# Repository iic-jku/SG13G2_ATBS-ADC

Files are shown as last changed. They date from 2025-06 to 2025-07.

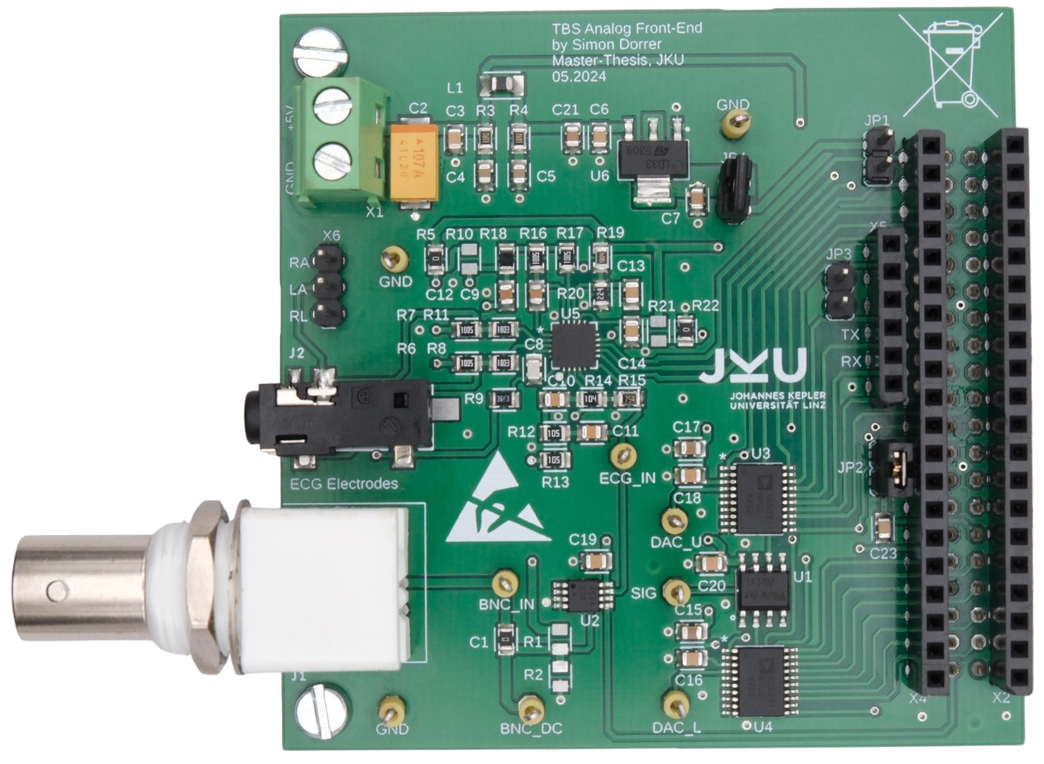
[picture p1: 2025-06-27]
PCB-Design/TBS_Analog_Front-End/TBS_Analog_Front-End_Pics/TBS_Analog_Front-End_TOP_3D_Foto.png

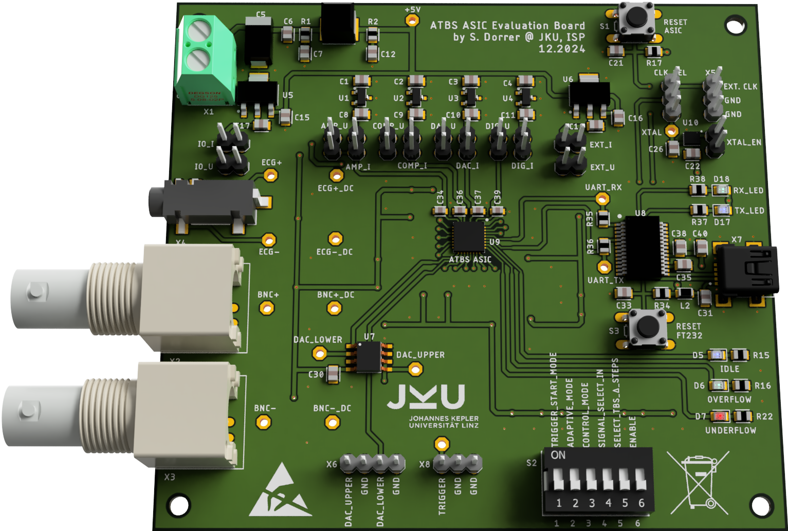
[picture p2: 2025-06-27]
PCB-Design/ATBS_Evaluation-Board/ATBS_Evaluation-Board_Pics/ATBS_Evaluation-Board_3D_Top.png

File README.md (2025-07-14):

# SG13G2_ATBS-ADC
**Author:** Simon Dorrer, 2024 / 2025, Johannes Kepler University (JKU) Linz, Austria, Institute for Integrated Circuits and Quantum Computing (IICQC) / Institute of Signal Processing (ISP). This ATBS-ADC has been designed in the context of a Master's thesis, it is published on https://epub.jku.at/obvulihs/content/titleinfo/12118473.

**Title:** An Open-Source Adaptive Event-Based ADC for Bio-Signal Acquisition in 130nm CMOS

**Abstract:**
Event-based ADCs offer significant advantages over Nyquist ADCs in applications where signals are sparse and exhibit substantial variations only within short time intervals, such as the QRS complex in an electrocardiogram (ECG). Unlike Nyquist ADCs, which sample data continuously at fixed rates and therefore often lead to unnecessary data and higher power consumption in time intervals of minimal signal variation, event-based ADCs only generate data when the signal exceeds a predefined voltage threshold. This makes them more energy-efficient, especially for battery-powered, wireless, and wearable devices, such as fitness trackers, medical sensors, and Internet of Things (IoT) devices. Adaptively adjusting these voltage thresholds further enhances efficiency.

This work first presents a PCB-level demonstrator to validate the feasibility of the event-based ADC concept. The demonstrator enables the development of a reconstruction framework for non-uniform data points in Matlab and Python and serves as a verification platform of the digital core on an FPGA.

Subsequently, an event-based ADC is integrated utilizing open-source tools and IHP's 130nm CMOS technology. The analog circuit design uses Xschem, Ngspice, and Jupyter notebooks with gm/ID sizing scripts. Furthermore, the design consists of a digital core written in VHDL. Since some open-source tools prefer Verilog, the VHDL code is converted to Verilog using GHDL. Simulations are conducted with GTKWave, Surfer, or ModelSim, while register-transfer level (RTL) synthesis is performed using Yosys. The synthesized digital design is included in Xschem using Qflow scripts and Xspice, enabling analog-mixed signal (AMS) simulations. The digital layout is created with OpenROAD Flow scripts (ORFS).

Finally, a pinout and a suitable package is suggested and a potential evaluation board for the designed ASIC is proposed.

**Cite this work:**

```
@online{Dorrer_2025_ATBS_ADC,
	author={Simon Dorrer},
	title={{An Open-Source Adaptive Event-Based ADC for Bio-Signal Acquisition in 130nm CMOS}},
	year={2025},
	url={https://github.com/iic-jku/SG13G2_ATBS-ADC}}
```

**Resources:**

- Master's Thesis: https://epub.jku.at/obvulihs/content/titleinfo/12118473
- Presentation at FSiC 2025: https://wiki.f-si.org/index.php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
- YouTube Video: coming soon on https://www.youtube.com/@Simi_OE3SDE
- GitHub Repository (SG13G2 ASIC Design Template):
  https://github.com/simi1505/SG13G2_ASIC-Design-Template

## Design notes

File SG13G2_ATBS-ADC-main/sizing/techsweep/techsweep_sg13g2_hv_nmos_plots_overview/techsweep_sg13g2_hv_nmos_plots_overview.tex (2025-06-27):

% !TeX TXS-program:compile = txs:///pdflatex/[--shell-escape]
%% !TeX document-id = {b8e7f259-21c3-4834-b29d-9cf620be8d99}

\documentclass[12pt]{article}

\usepackage[utf8]{inputenc}
\usepackage[T1]{fontenc}
\usepackage[ngerman, english]{babel}
\usepackage{lmodern}
\usepackage{geometry}
\usepackage{amsmath}
\usepackage{float}
\usepackage{graphicx}
\usepackage{subfig}

\begin{document}
	
	\oddsidemargin 0mm
	\parindent 0pt
	\newgeometry{top=2cm, bottom=2cm, left=2.6cm, right=3cm, footskip=30pt}
	
	\begin{figure}[!ht]
		\centering
		\vspace*{-18px}
		\subfloat[][]{}
		\hfill
		\subfloat[][]{} \\ \vspace{-10px}
		\subfloat[][]{}
		\hfill
		\subfloat[][Modelling issue]{} \\ \vspace{-10px}
		\subfloat[][]{}
		\hfill
		\subfloat[][]{} \\ \vspace{-10px}
		\subfloat[][]{}
		\hfill
		\subfloat[][]{}
		\caption{Characterization plots of a SG13G2 HV NMOST for the $g_\mathrm{m} / I_\mathrm{D}$ methodology.}
		\label{fig:NMOS_gmID_plots}
	\end{figure}
\end{document}

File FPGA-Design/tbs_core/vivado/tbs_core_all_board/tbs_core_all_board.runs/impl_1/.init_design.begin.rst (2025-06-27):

<?xml version="1.0"?>
<ProcessHandle Version="1" Minor="0">
    <Process Command=".planAhead." Owner="si150" Host="SIMIBOOK" Pid="18372">
    </Process>
</ProcessHandle>

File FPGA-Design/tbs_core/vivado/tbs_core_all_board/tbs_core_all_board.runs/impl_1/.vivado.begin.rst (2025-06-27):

<?xml version="1.0"?>
<ProcessHandle Version="1" Minor="0">
    <Process Command="vivado.bat" Owner="si150" Host="SIMIBOOK" Pid="11472" HostCore="16" HostMemory="016458313728">
    </Process>
</ProcessHandle>
<?xml version="1.0"?>
<ProcessHandle Version="1" Minor="0">
    <Process Command="vivado.bat" Owner="si150" Host="SIMIBOOK" Pid="11940" HostCore="16" HostMemory="016458313728">
    </Process>
</ProcessHandle>
<?xml version="1.0"?>
<ProcessHandle Version="1" Minor="0">
    <Process Command="vivado.bat" Owner="si150" Host="SIMIBOOK" Pid="7340" HostCore="16" HostMemory="016458313728">
    </Process>
</ProcessHandle>

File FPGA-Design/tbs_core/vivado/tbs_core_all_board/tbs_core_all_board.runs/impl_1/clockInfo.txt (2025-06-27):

-------------------------------------
| Tool Version : Vivado v.2024.1
| Date         : Tue Mar 25 13:14:02 2025
| Host         : SimiBook
| Design       : design_1
| Device       : xc7s25-ftgb196-1--
-------------------------------------

For more information on clockInfo.txt clock routing debug file see https://support.xilinx.com/s/article/000035660?language=en_US

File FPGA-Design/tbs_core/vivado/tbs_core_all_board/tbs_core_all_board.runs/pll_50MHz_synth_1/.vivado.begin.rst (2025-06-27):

<?xml version="1.0"?>
<ProcessHandle Version="1" Minor="0">
    <Process Command="vivado.bat" Owner="si150" Host="SIMIBOOK" Pid="6616" HostCore="16" HostMemory="016458313728">
    </Process>
</ProcessHandle>

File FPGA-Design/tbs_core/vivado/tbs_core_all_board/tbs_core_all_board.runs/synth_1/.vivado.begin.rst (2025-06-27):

<?xml version="1.0"?>
<ProcessHandle Version="1" Minor="0">
    <Process Command="vivado.bat" Owner="si150" Host="SIMIBOOK" Pid="9116" HostCore="16" HostMemory="016458313728">
    </Process>
</ProcessHandle>

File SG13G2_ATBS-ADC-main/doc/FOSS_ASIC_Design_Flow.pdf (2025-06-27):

# FOSS ASIC DESIGN

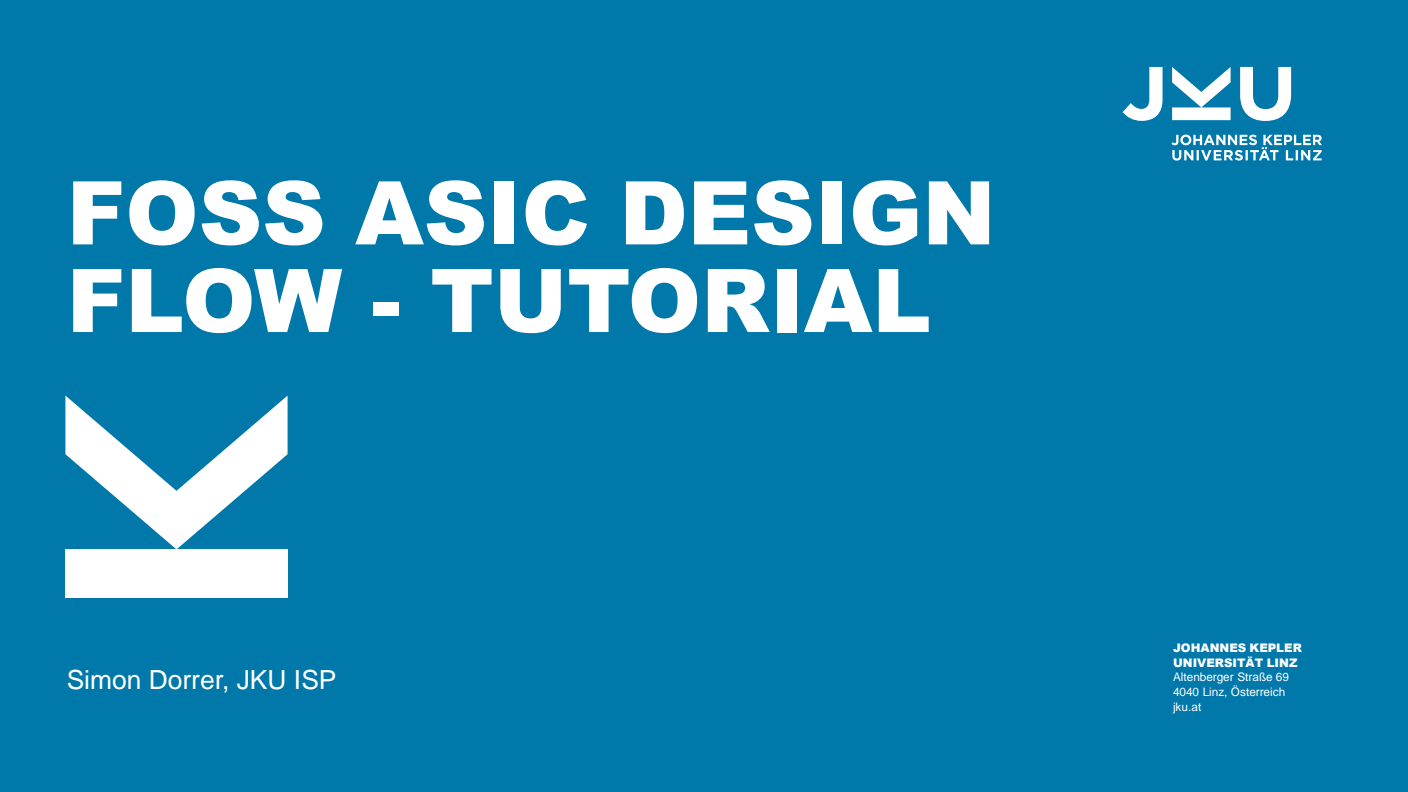
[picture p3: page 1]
JOHANNES KEPLER UNIVERSITÄT LINZ Altenberger Straße 69 4040 Linz, Österreich; jku.at; FLOW - TUTORIAL

Simon Dorrer, JKU ISP

## 1.) Free and open-source software (FOSS)

- GHDL: VHDL analyzer, compiler, simulator and synthesizer
- YOSYS: Verilog synthesis tool (with GHDL plugin for VHDL synthesis)
- Magic: layout editor with DRC and PEX
- Klayout: layout viewer and editor for GDS and OASIS
- OpenRAM: Python library for RAM block generation
- Xschem: Schematic editor for analog circuit design
- Openlane: Digital RTL2GDS flow
- IIC-OSIC-Tools:
- https://github.com/iic-jku/iic-osic-tools
- all-in-one Docker container for FOSS based IC designs for analog and digital circuit flows

## 2.) Installed open-source PDKs

- PDK: process-development kits
- https://en.wikipedia.org/wiki/Process_design_kit
- a set of files used within the semiconductor industry to model a fabrication process for the

design tools used to design an integrated circuit

- Symbols, Device Parameters
- Design Rule Check (DRC), Layout vs. Schematic (LVS), Electrical Rule Check (ERC)
- Simulation models for components (e.g. spice)
- Skywater 130nm Technology: https://www.skywatertechnology.com/
- Global Foundries 180nm Technology: https://gf.com/de/
- IHP Microelectronics 130nm Technology: https://www.ihp-microelectronics.com/de

## 3.) Where to tape out?

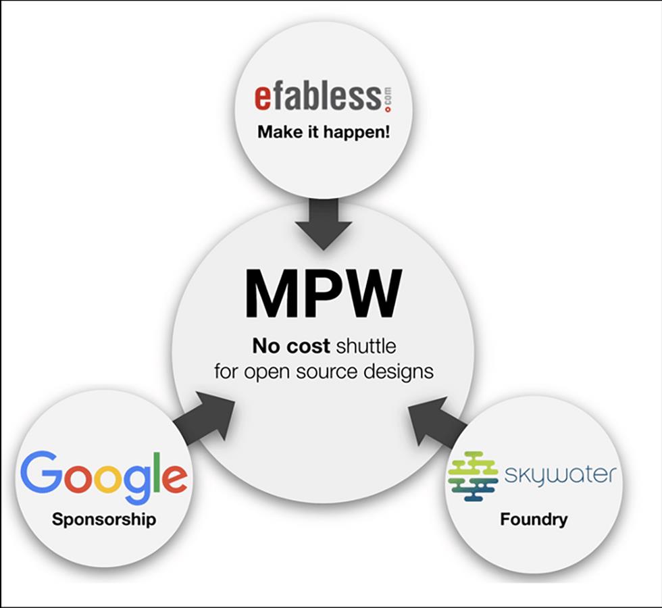
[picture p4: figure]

- Efabless Open MPW Program:
- https://efabless.com/open_shuttle_program
- PDK from skywater
- Chip manufactured by Efabless
- Google coveres costs for fabrication, packaging,

evaluation boards and shipping

- Tiny Tapeout 3:
- https://tinytapeout.com/
- PDK from skywater
- Chip manufactured by Efabless
- Extremely cheap, since more projects are put on one chip

## 4.) GHDL

- Github: https://github.com/ghdl/ghdl
- Documentation: https://ghdl.github.io/ghdl/about.html

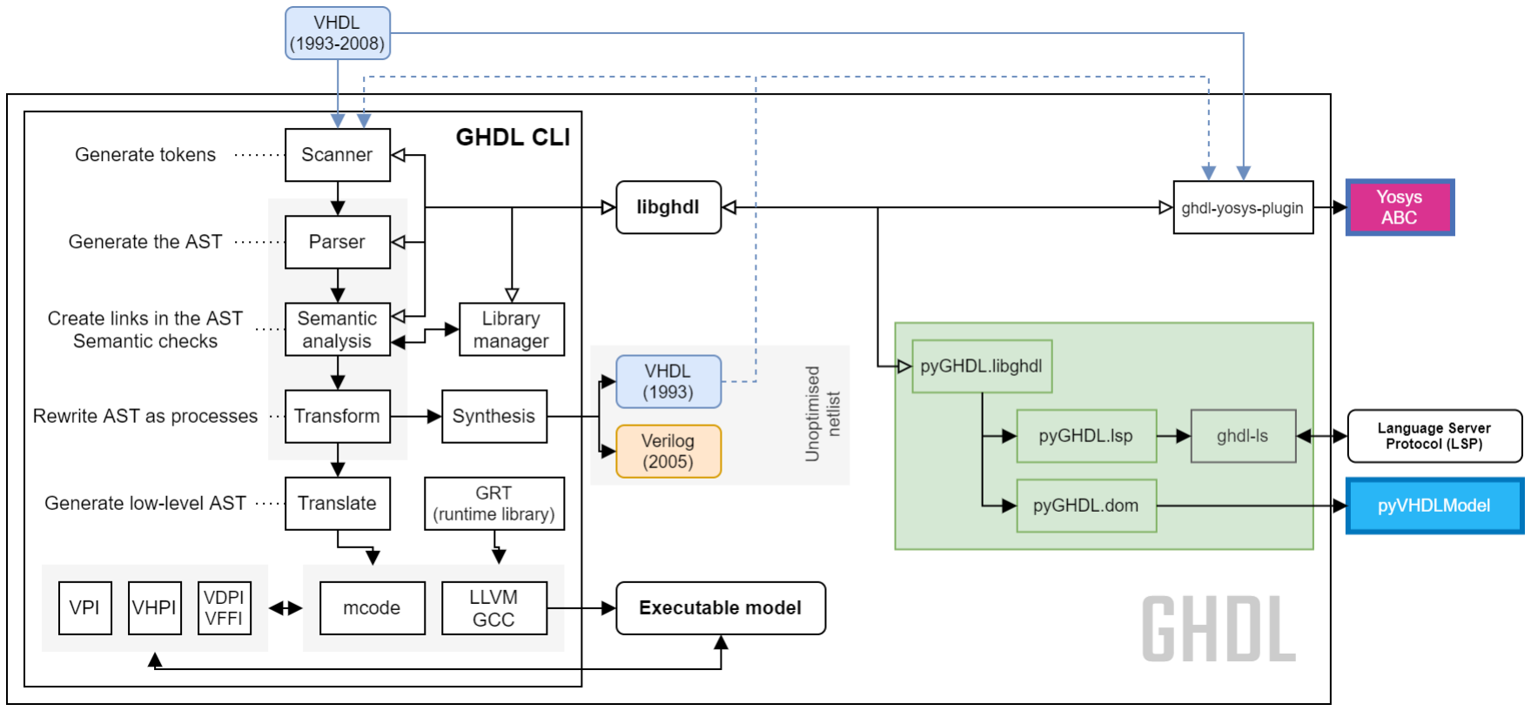
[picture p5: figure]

## 5.) Yosys

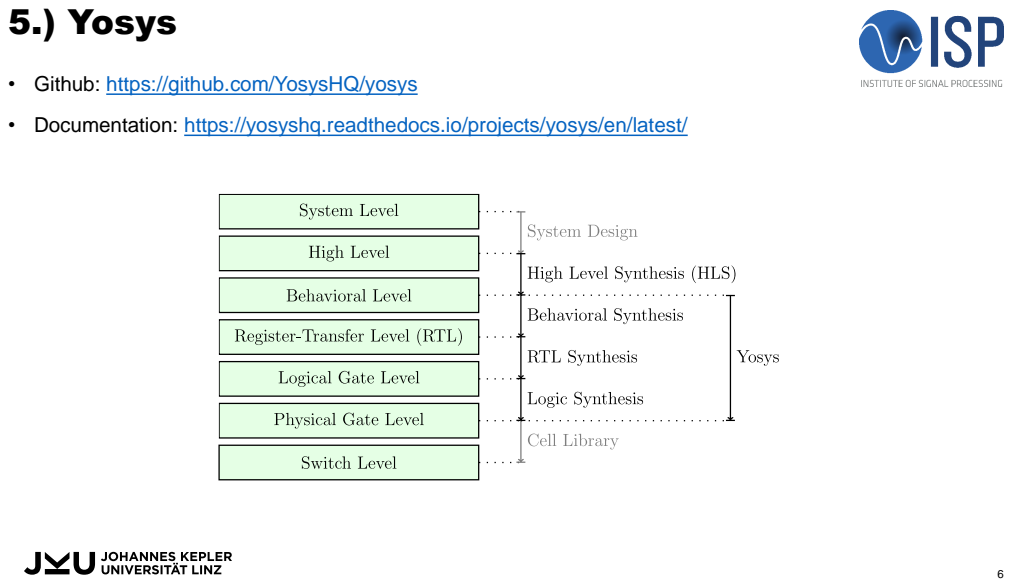
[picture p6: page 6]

• Github: https://github.com/YosysHQ/yosys

• Documentation: https://yosyshq.readthedocs.io/projects/yosys/en/latest/

# 6.) OpenLane – Intro

- Github: https://github.com/The-OpenROAD-Project/OpenLane
- Documentation: https://ghdl.github.io/ghdl/about.html
- Yosys, magic, and so on are used by OpenLane
- OpenROAD is one of the tools used by the OpenLane flow

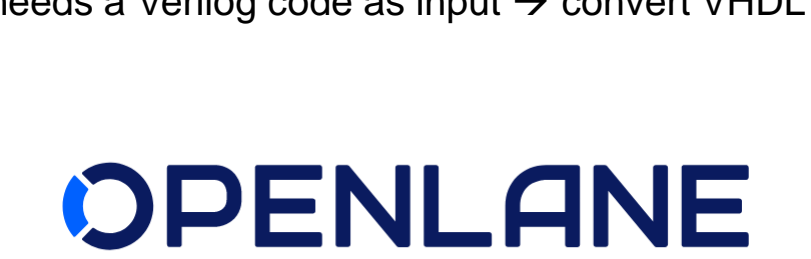
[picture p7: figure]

- The OpenLane flow needs a Verilog code as input → convert VHDL to Verilog with GHDL

## 6.) OpenLane – Flow Diagram

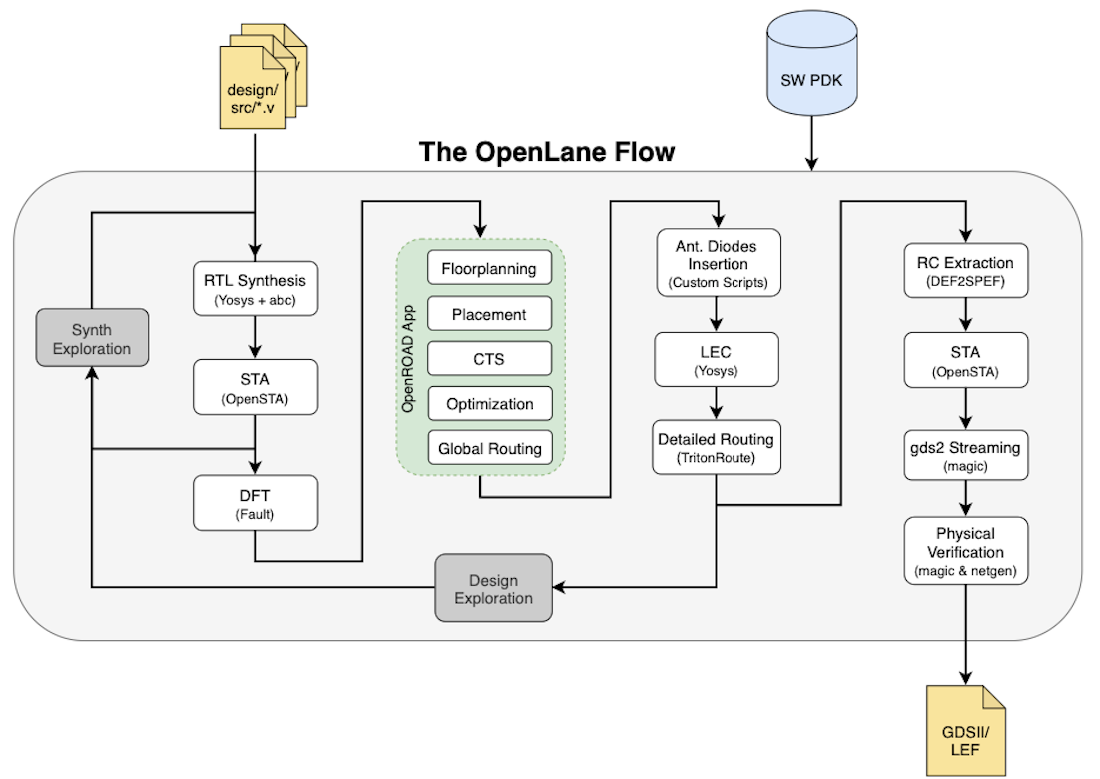
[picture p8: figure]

## 6.) OpenLane – Design Stages

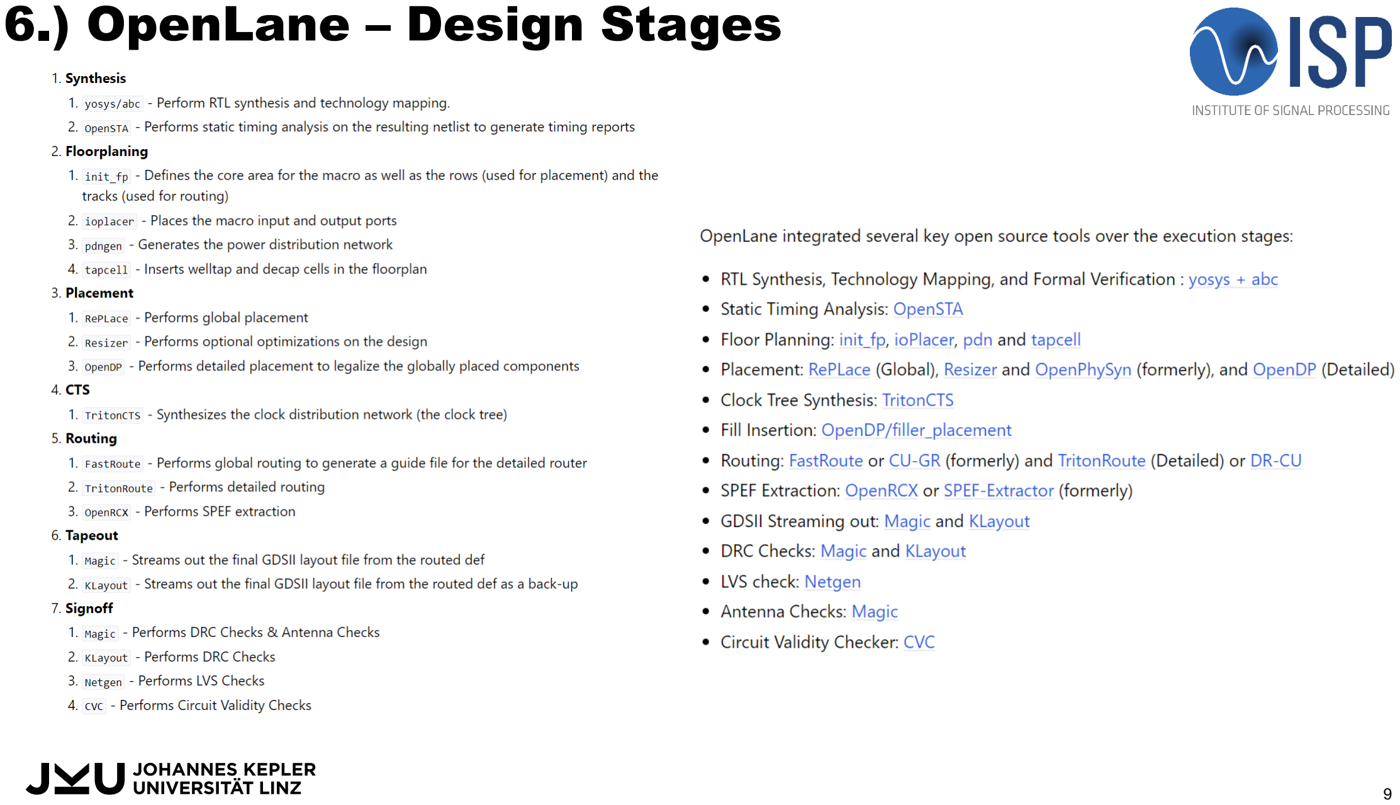
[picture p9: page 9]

## 6.) OpenLane – Output

- All output run data is placed by default under “./designs/design_name/runs”
- Each flow cycle will output a timestamp-marked folder containing the following file structure:

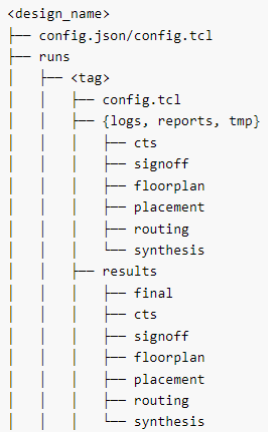
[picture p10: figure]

## 7.) Examples – IIC

- SAR-ADC: https://github.com/iic-jku/SKY130_SAR-ADC1
- Synthesizable Digital Temperature Sensor: https://github.com/iic-jku/tt03-tempsensor

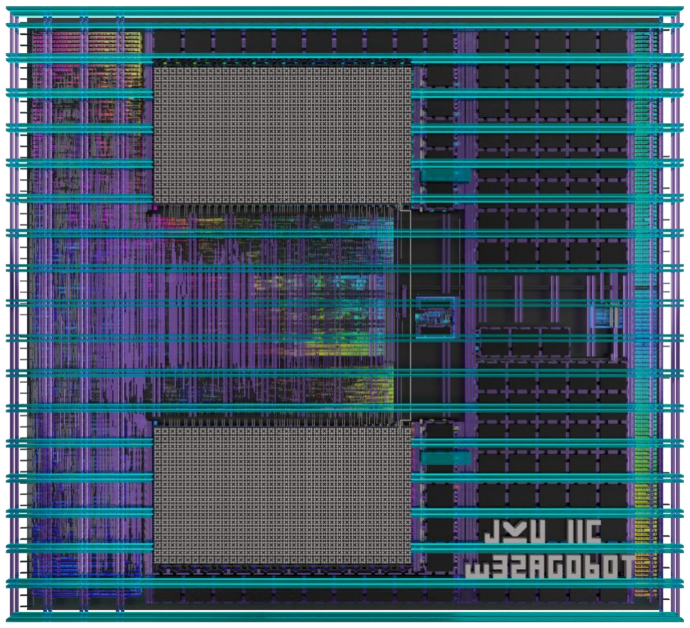
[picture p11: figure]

## 7.) Examples - Efabless Open MPW Program

- MPW-8 projects: https://platform.efabless.com/projects/shuttle/14

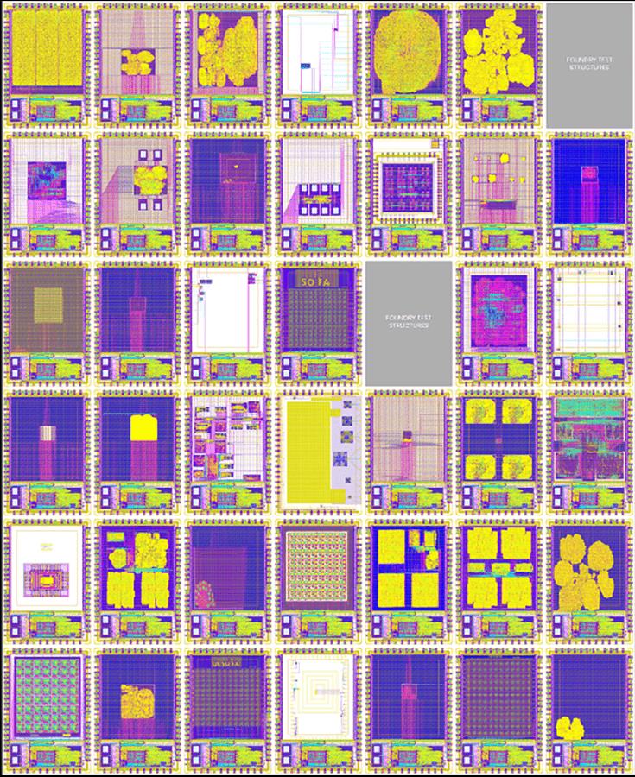
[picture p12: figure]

## 7.) Examples – Tiny Tapeout

- Tiny Tapeout 3 projects: https://tinytapeout.com/runs/tt03/

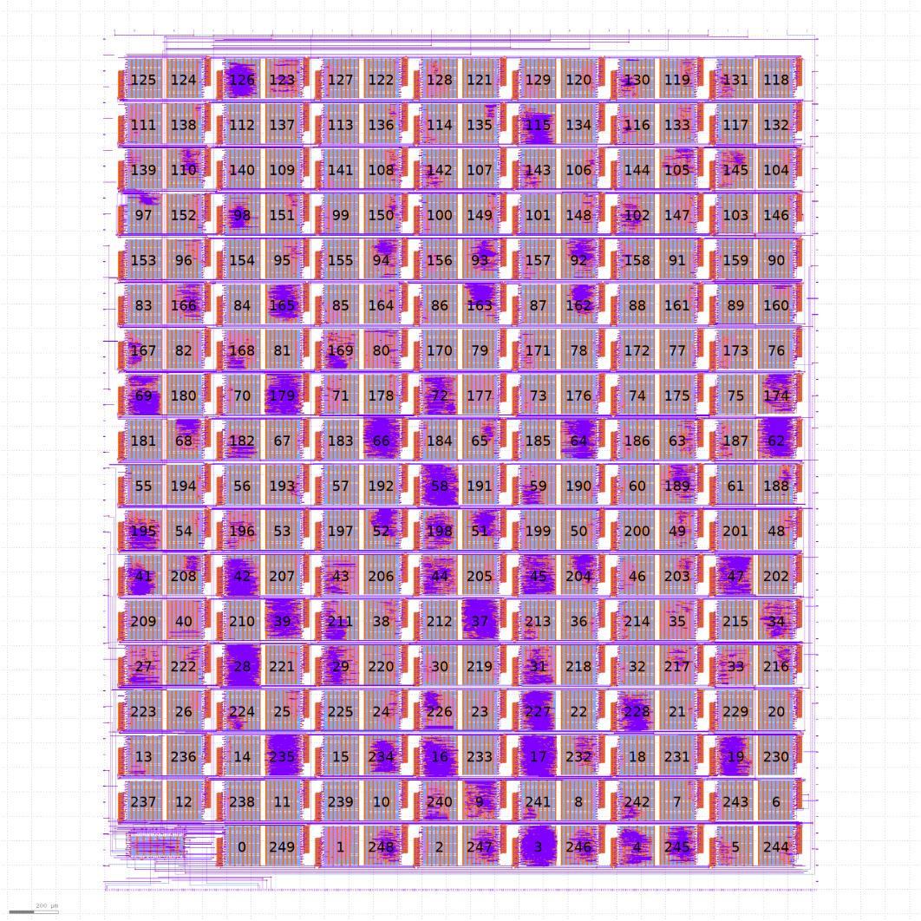
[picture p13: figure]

## 8.) Tutorial – Setting up Docker container

- Install Docker: https://docs.docker.com/desktop/install/windows-install/
- Install Xming X-server: https://sourceforge.net/projects/xming/
- Download IIC-OSIC-TOOLS: https://github.com/iic-jku/iic-osic-tools
- Set up the environment
- Please, do the step-by-step instruction shown in “EIS-KV_Docker-Tutorial.pdf”

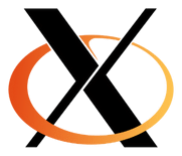
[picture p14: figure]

- X-server or XVNC (WebApp, PW: abc123)

## 8.) Tutorial – Recommended Workflow

- 1.) Write VHDL Design
- 2.) Simulate VHDL Design in ModelSim
- 3.) Synthesize VHDL Design in Quartus
- 4.) Test VHDL Design on FPGA Board
- 5.) Convert VHDL Design to Verilog Design with GHDL
- 6.) Simulate Verilog Design in ModelSim
- 7.) Synthesize Verilog Design in Quartus
- 8.) Compare hardware resources of VHDL and Verilog Quartus Projects
- 9.) Test Verilog Design on FPGA Board
- 10.) Use Yosys to read the Verilog File and output stats and .svg files
- 11.) Use OpenLane for open-source ASIC Design
- 12.) Take Skywater 130nm Verilog netlist and simulate the design again (Post-Layout Simulation)

## 8.) Tutorial – Basic Commands

- Enter the next folder with ”cd folder_name“ and go back with ”cd ..“.
- After some minutes of inactivity, the X-server closes itself. Just open the task manager with

”htop“ in a new tab to prevent this.

- If an application (e.g. simulation, yosys) should be closed, just enter STRG+C.

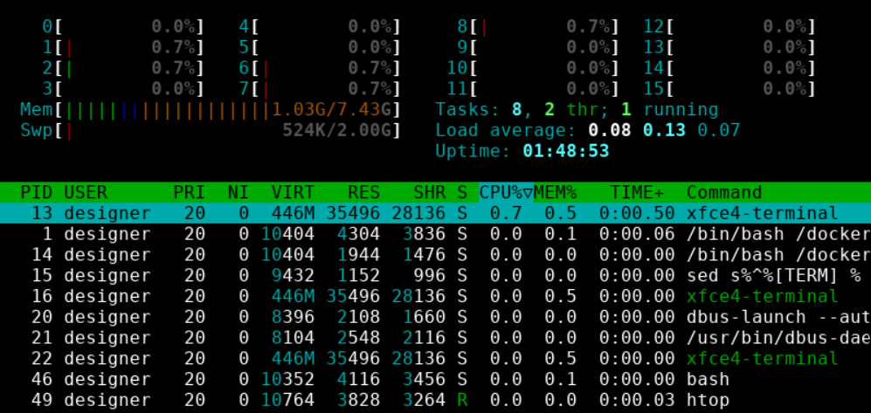
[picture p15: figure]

## 8.) Tutorial – Compilation / Simulation

- If the architecture is finished, it should be compiled and checked for syntax errors.
- This can be done with the command “iic-vlint.sh <file.v>“
- After the architecture is without syntax errors, it should be simulated with its according testbench.
- With the self-written shell, this can be done very easily, just call “./simulate.sh <file>“.
- After a simulation is set up it can be saved with STRG+S and re-loaded with STRG+O again.
- A simulation file is saved as „wave.gtkw“ by default

## 8.) Tutorial – Compilation / Simulation

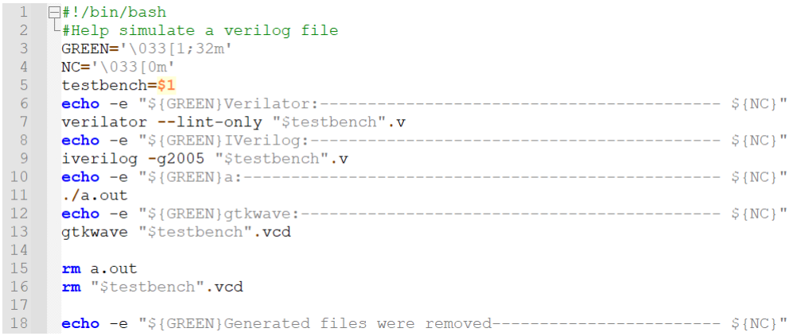
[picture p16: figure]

## 8.) Tutorial – Compilation / Simulation

- Simulation of counter example

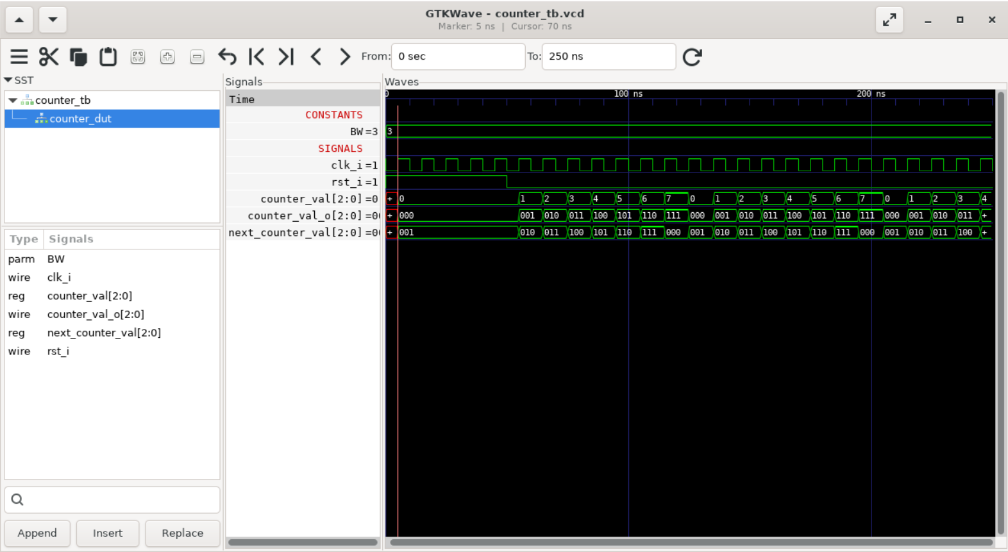
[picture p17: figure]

## 8.) Tutorial – Convert VHDL to Verilog

- In order to convert the VHDL files to one file of Verilog code, a shell script should be written.
- For this tutorial the shell script (convert.sh) is already written and can be used as a template for

upcoming projects.

- All the commands and parameters can be found in the GHDL manual
- Execute the shell with “sh convert.sh”
- For single files: yosys -m ghdl -p 'ghdl filename.vhd -e entityname; write_verilog filename.v'
- In order to test the Verilog code, one can synthesize the created code in Quartus and test it on a

FPGA board and / or compare the amount of ALMs and registers.

## 8.) Tutorial – Convert VHDL to Verilog

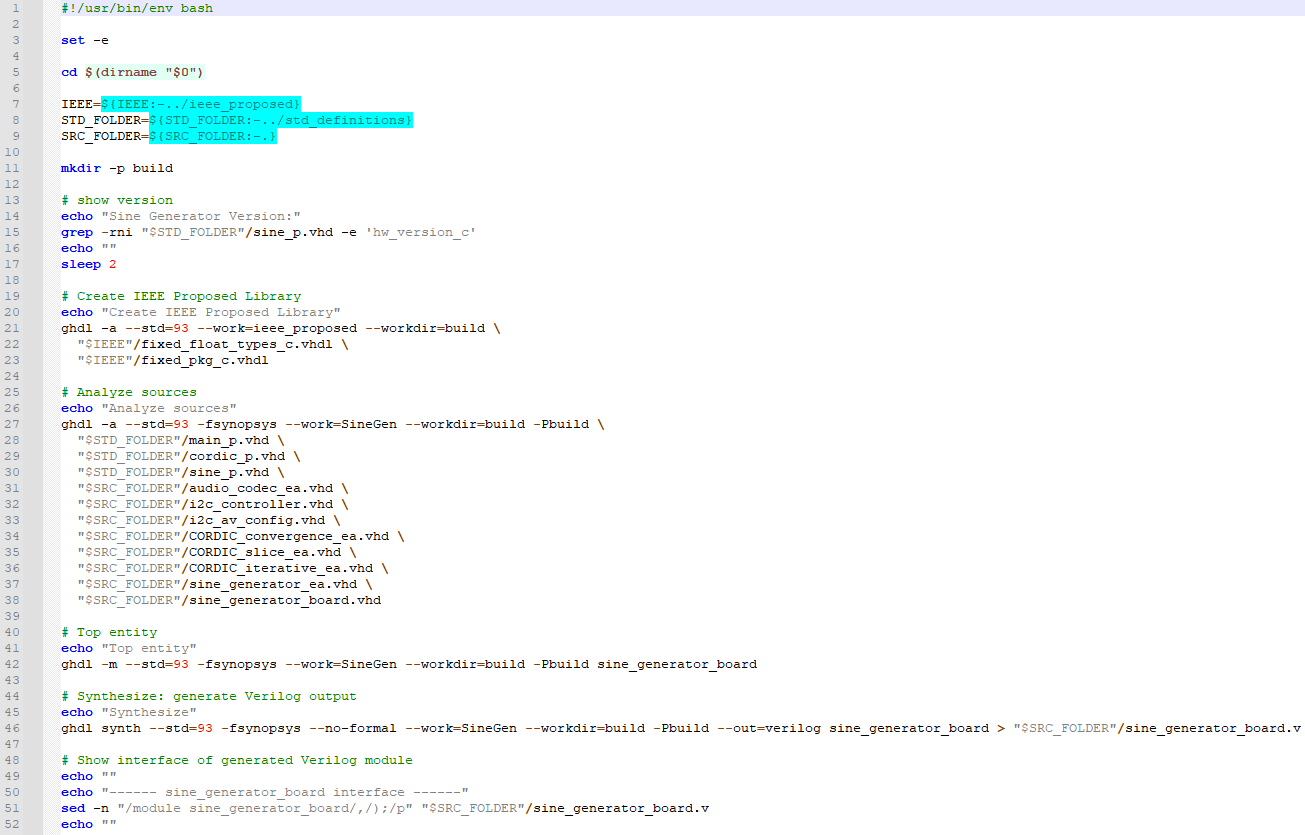
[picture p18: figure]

## 8.) Tutorial – Showing Stats

### - The following figure shows the sequence of CMD commands to output the

needed hardware for the written architecture.

## 8.) Tutorial – Showing Stats

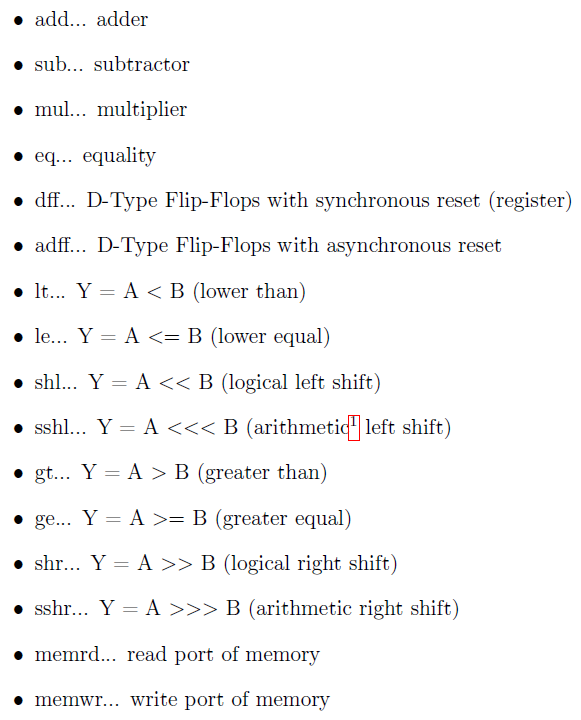
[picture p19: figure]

- The $memwr cells have a clock input CLK, an enable

input EN (one enable bit for each data bit), an address

input ADDR and a data input DATA.

- The $memrd cells have a clock input CLK, an enable

input EN, an address input ADDR and a data output

DATA.

- More informations can be found in the yosys manual,

just search for „$abbreviation_name“.

## 8.) Tutorial – Drawing RTL View

### - The following figure shows the sequence of CMD commands to create the RTL

view in .svg file format.

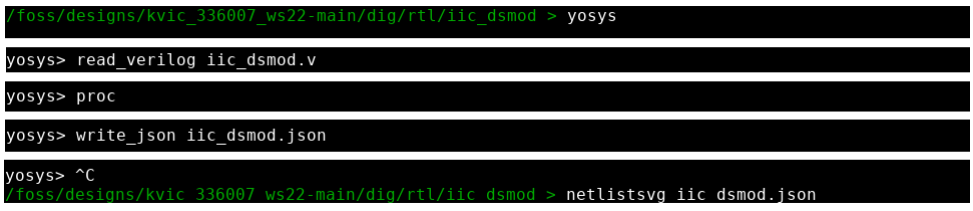
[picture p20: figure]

## 8.) Tutorial – Drawing RTL View

### - RTL view of the counter tutorial

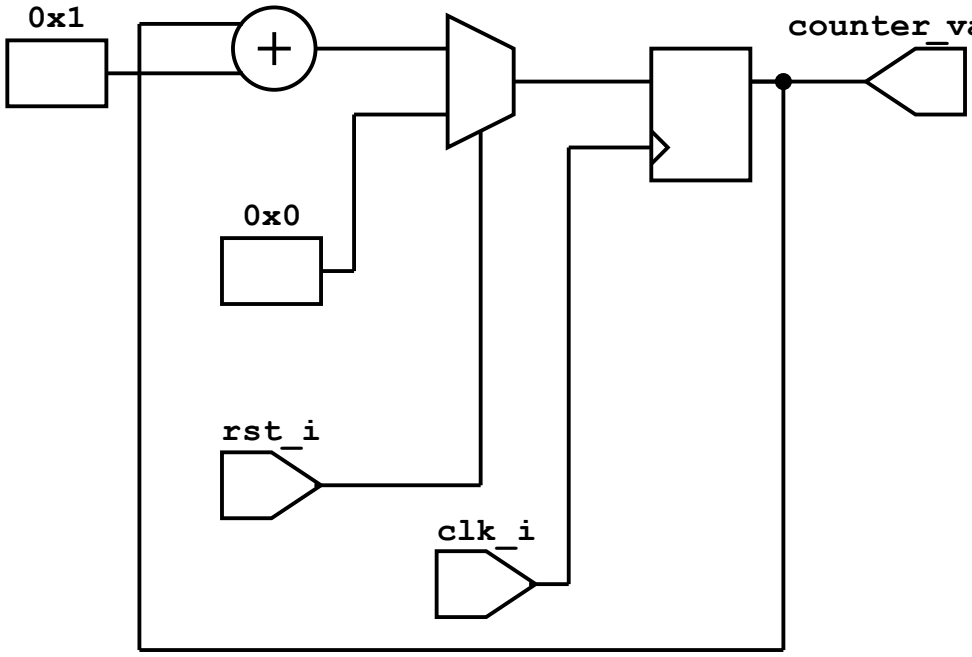
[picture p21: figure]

## 8.) Tutorial – Drawing RTL View

### - RTL view of a digital Sigma Delta Modulator with FIFO and Sinegen

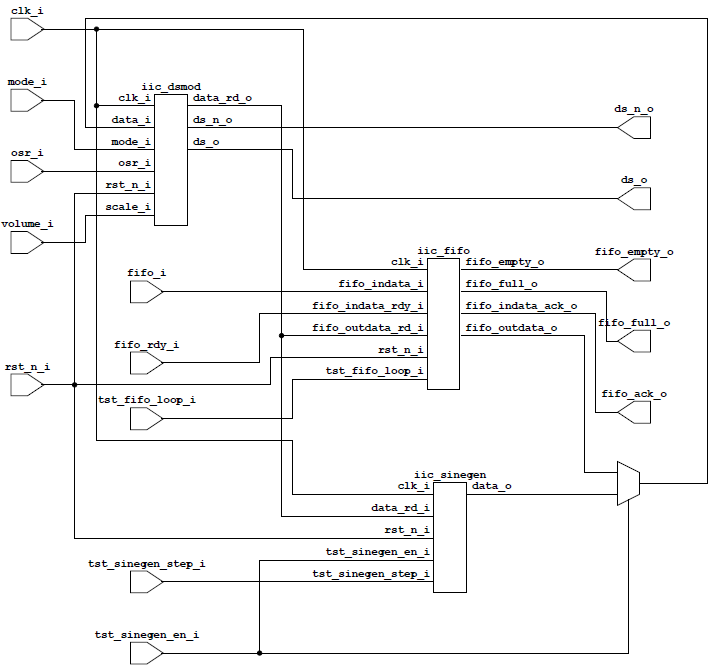
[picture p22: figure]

## 8.) Tutorial – Compare VHDL / Verilog

- Mixed VHDL / Verilog Simulation with ModelSim

## 8.) Tutorial – Compare VHDL / Verilog

- Left: VHDL
- Right: Verilog

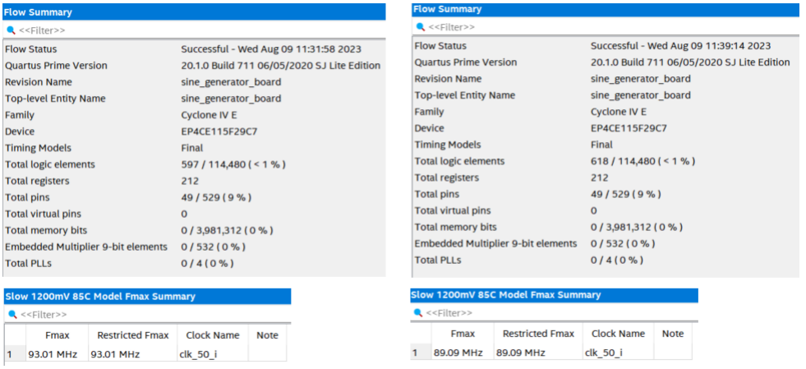
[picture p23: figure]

## 8.) Tutorial – OpenLane

- In the „config.json“ file the parameters for the digital layout is set.
- CLOCK_PERIOD (to achieve a fast enough design)
- FP_CORE_UTIL, FP_IO_MIN_DISTANCE, PLACE_DENSITY, …
- The manual and ChatGPT can help out here ☺
- In order to create the IC design, one must navigate to the folder with the config files and

execute the command „flow.tcl -designs .“.

- After some minutes / hours, the design should be created and it can be viewed with the

tool „magic“ or „klayout“.

- In „magic“, one can zoom after creating a box by a left click and a right click and pressing

STRG+Z. The full view can be established again by pressing the key „f“.

- Please see the “magic_cheatsheet.pdf” for further commands!

## 8.) Tutorial – OpenLane

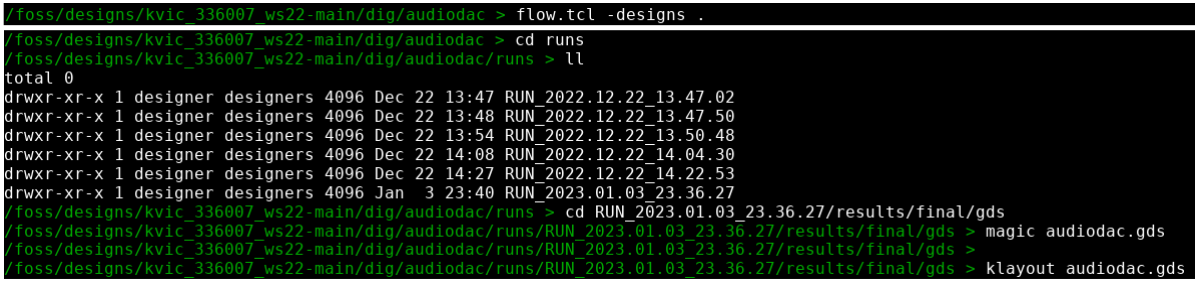
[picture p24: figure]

- Verilog: “./designs/design_name/runs/RUN_XYZ/results/final/verilog”
- GDS: “./designs/design_name/runs/RUN_XYZ/results/final/gds”
- Reports: “./designs/design_name/runs/RUN_XYZ/reports”

## 8.) Tutorial – OpenLane

### - Final digital layout of the sine generator using a 16-Bit CORDIC

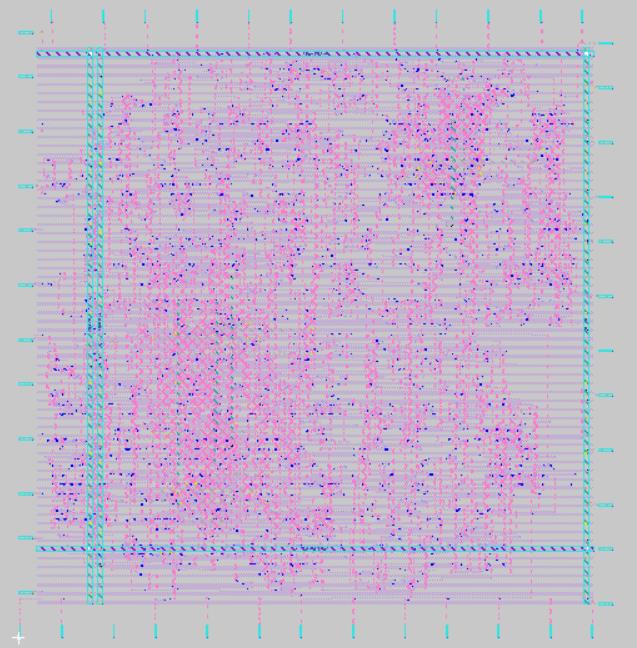
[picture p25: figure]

## 8.) Tutorial – Sine Generator with CORDIC

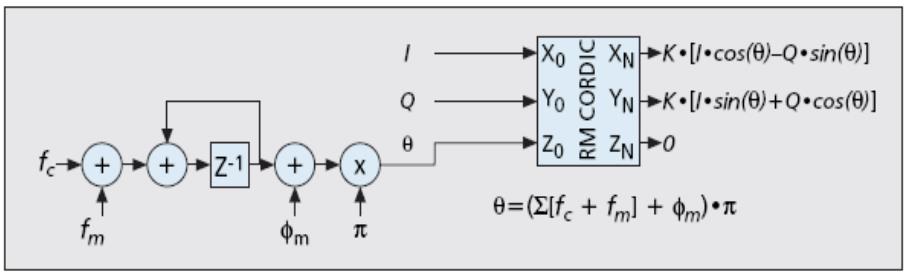
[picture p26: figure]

### - To generate sine and cosine waveforms of a digital frequency fc with the generic

### scheme above, we can choose:

### - I = 1/K and Q = 0

### - fm = 0, φm = 0

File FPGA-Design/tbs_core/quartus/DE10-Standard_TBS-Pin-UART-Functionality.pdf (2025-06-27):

Type | Name | Func | Description
Button | KEY0 | reset | reset
Button | KEY1 | trigger_start_sampling | manual sampling trigger (optional, instead of AWG trigger)
Switch | SW0 | trigger_start_mode | '1' Start sampling on trigger - '0' Start sampling directly
Switch | SW1 | adaptive_mode | '1' ATBS - '0' TBS
Switch | SW2 | control_mode | '1' UART - '0' Switches
Switch | SW3 | signal_select_in | '1' BNC - '0' ECG
Switch | SW4 | enable | '1' Enable - '0' Disable
Switch | SW5 | select_tbs_delta_steps | '1' "virtual" DAC resolution - '0' full DAC resolution
Switch | SW6 | select_comparator_type | '1' Modeling DT comparator - '0' Modeling CT comparator
UART | - | trigger_start_mode | '1' Start sampling on trigger - '0' Start sampling directly
UART | - | adaptive_mode | '3' ATBS - '2' TBS
UART | - | signal_select_in | '5' BNC - '4' ECG
UART | - | enable | '7' Enable - '6' Disable
UART | - | select_tbs_delta_steps | '9' "virtual" DAC resolution - '8' full DAC resolution
UART | - | update config. | 'U'
UART | - | start sampling | 'S' (enter 2x)
UART | - | reset | 'R'
UART | - | analog trigger settings | 'T' and 'a' to 'f'
UART | - | SC NOC generator settings | 'C' and 'a' to 'c'
UART | - | UART baudrate | 'B' and 'a' to 'd'

# Adaptive Threshold Based Sampling

### Cyclone V: 5CSXFC6D6F31C6 (DE10-Standard FPGA Board)

Type | Name | Func | Description
UART | - | TBS virtual delta steps | 'V' and 'a' to 'e'
UART | - | ATBS win_length / time_win | 'W' and 'a' to 'd'
UART | - | ATBS deltasteps_max | 'D' and 'a' to 'e'
LED | LEDR0 | idle | '1'... Lights up, if Main FSM is in idle state!
LED | LEDR1 | overflow | '1'... Lights up, if FIFO is full!
LED | LEDR2 | underflow | '1'... Lights up, if FIFO is empty!
LED | LEDR3 | ecg | '1'... Lights up, if ECG electrodes are connected!

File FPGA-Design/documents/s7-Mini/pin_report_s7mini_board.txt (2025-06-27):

Copyright 1986-2020 Xilinx, Inc. All Rights Reserved.
-------------------------------------------------------------------------------------------------
| Tool Version              : Vivado v.2020.2 (win64) Build 3064766 Wed Nov 18 09:12:45 MST 2020
| Date                      : Wed Jul 17 09:56:46 2024
| Host                      : Inspiron_6 running 64-bit major release  (build 9200)
| Command                   : report_io -file tbs_board_io_placed.rpt
| Design                    : tbs_board
| Device                    : xc7s25
| Speed File                : -1
| Package                   : ftgb196
| Package Version           : PRODUCTION 1.1 11/06/2017
| Package Pin Delay Version : PRODUCTION 1.0 6/7/2017
-------------------------------------------------------------------------------------------------

IO Information

Table of Contents
-----------------
1. Summary
2. IO Assignments by Package Pin

1. Summary
----------

+---------------+
| Total User IO |
+---------------+
|            21 |
+---------------+

2. IO Assignments by Package Pin
--------------------------------

+------------+--------------------------+------------+------------------------------+-------------+-------------+---------+------------+------+---------------------+----------------------+---------+------------+-----------+----------+------+------------------+--------------+-------------------+--------------+
| Pin Number | Signal Name              | Bank Type  | Pin Name                     | Use         | IO Standard | IO Bank | Drive (mA) | Slew | On-Chip Termination | Off-Chip Termination | Voltage | Constraint | Pull Type | DQS Bias | Vref | Signal Integrity | Pre Emphasis | Lvds Pre Emphasis | Equalization |
+------------+--------------------------+------------+------------------------------+-------------+-------------+---------+------------+------+---------------------+----------------------+---------+------------+-----------+----------+------+------------------+--------------+-------------------+--------------+
| A1         |                          |            | GND                          | GND         |             |         |            |      |                     |                      |     0.0 |            |           |          |      |                  |              |                   |              |
| A2         | input_analog_o           | High Range | IO_L3N_T0_DQS_34             | OUTPUT      | LVCMOS33    |      34 |         12 | SLOW |                     |            FP_VTT_50 |         | FIXED      |           |          |      | NONE             |              |                   |              |
| A3         | charge_direction_lower_o | High Range | IO_L2N_T0_34                 | OUTPUT      | LVCMOS33    |      34 |         12 | SLOW |                     |            FP_VTT_50 |         | FIXED      |           |          |      | NONE             |              |                   |              |
| A4         |                          | High Range | IO_L2P_T0_34                 | User IO     |             |      34 |            |      |                     |                      |         |            |           |          |      |                  |              |                   |              |
| A5         |                          | High Range | IO_L4N_T0_34                 | User IO     |             |      34 |            |      |                     |                      |         |            |           |          |      |                  |              |                   |              |
| A6         |                          |            | GND                          | GND         |             |         |            |      |                     |                      |     0.0 |            |           |          |      |                  |              |                   |              |
| A7         |                          | Dedicated  | TCK_0                        | Config      |             |       0 |            |      |                     |                      |         |            |           |          |      |                  |              |                   |              |
| A8         |                          | Dedicated  | CCLK_0                       | Config      |             |       0 |            |      |                     |                      |         |            |           |          |      |                  |              |                   |              |
| A9         |                          |            | GND                          | GND         |             |         |            |      |                     |                      |     0.0 |            |           |          |      |                  |              |                   |              |
| A10        |                          | High Range | IO_L3N_T0_DQS_EMCCLK_14      | User IO     |             |      14 |            |      |                     |                      |         |            |           |          |      |                  |              |                   |              |
| A11        |                          |            | GND                          | GND         |             |         |            |      |                     |                      |     0.0 |            |           |          |      |                  |              |                   |              |
| A12        |                          | High Range | IO_L4P_T0_D04_14             | User IO     |             |      14 |            |      |                     |                      |         |            |           |          |      |                  |              |                   |              |
| A13        |                          | High Range | IO_L4N_T0_D05_14             | User IO     |             |      14 |            |      |                     |                      |         |            |           |          |      |                  |              |                   |              |
| A14        |                          |            | GND                          | GND         |             |         |            |      |                     |                      |     0.0 |            |           |          |      |                  |              |                   |              |
| B1         |                          | High Range | IO_L5N_T0_34                 | User IO     |             |      34 |            |      |                     |                      |         |            |           |          |      |                  |              |                   |              |
| B2         | comp_lower_i             | High Range | IO_L5P_T0_34                 | INPUT       | LVCMOS33    |      34 |            |      |                     |                 NONE |         | FIXED      |           |          |      | NONE             |              |                   |              |
| B3         |                          | High Range | IO_L3P_T0_DQS_34             | User IO     |             |      34 |            |      |                     |                      |         |            |           |          |      |                  |              |                   |              |
| B4         |                          |            | GND                          | GND         |             |         |            |      |                     |                      |     0.0 |            |           |          |      |                  |              |                   |              |
| B5         |                          | High Range | IO_L4P_T0_34                 | User IO     |             |      34 |            |      |                     |                      |         |            |           |          |      |                  |              |                   |              |
| B6         |                          | High Range | IO_0_34                      | User IO     |             |      34 |            |      |                     |                      |         |            |           |          |      |                  |              |                   |              |
| B7         |                          |            | GND                          | GND         |             |         |            |      |                     |                      |     0.0 |            |           |          |      |                  |              |                   |              |
| B8         |                          | Dedicated  | VCCBATT_0                    | Config      |             |       0 |            |      |                     |                      |         |            |           |          |      |                  |              |                   |              |
| B9         |                          |            | GND                          | GND         |             |         |            |      |                     |                      |     0.0 |            |           |          |      |                  |              |                   |              |
| B10        |                          | High Range | IO_L3P_T0_DQS_PUDC_B_14      | User IO     |             |      14 |            |      |                     |                      |         |            |           |          |      |                  |              |                   |              |
| B11        |                          | High Range | IO_L1P_T0_D00_MOSI_14        | User IO     |             |      14 |            |      |                     |                      |         |            |           |          |      |                  |              |                   |              |
| B12        |                          | High Range | IO_L1N_T0_D01_DIN_14         | User IO     |             |      14 |            |      |                     |                      |         |            |           |          |      |                  |              |                   |              |
| B13        |                          | High Range | IO_L5P_T0_D06_14             | User IO     |             |      14 |            |      |                     |                      |         |            |           |          |      |                  |              |                   |              |
| B14        |                          | High Range | IO_L5N_T0_D07_14             | User IO     |             |      14 |            |      |                     |                      |         |            |           |          |      |                  |              |                   |              |
| C1         | comp_upper_i             | High Range | IO_L11N_T1_SRCC_34           | INPUT       | LVCMOS33    |      34 |            |      |                     |                 NONE |         | FIXED      |           |          |      | NONE             |              |                   |              |
| C2         |                          |            | GND                          | GND         |             |         |            |      |                     |                      |     0.0 |            |           |          |      |                  |              |                   |              |
| C3         |                          | High Range | IO_L1N_T0_34                 | User IO     |             |      34 |            |      |                     |                      |         |            |           |          |      |                  |              |                   |              |
| C4         | enable_analog_o          | High Range | IO_L6N_T0_VREF_34            | OUTPUT      | LVCMOS33    |      34 |         12 | SLOW |                     |            FP_VTT_50 |         | FIXED      |           |          |      | NONE             |              |                   |              |
| C5         |                          | High Range | IO_L6P_T0_34                 | User IO     |             |      34 |            |      |                     |                      |         |            |           |          |      |                  |              |                   |              |
| C6         |                          |            | GND                          | GND         |             |         |            |      |                     |                      |     0.0 |            |           |          |      |                  |              |                   |              |
| C7         |                          |            | GND                          | GND         |             |         |            |      |                     |                      |     0.0 |            |           |          |      |                  |              |                   |              |
| C8         |                          |            | GND                          | GND         |             |         |            |      |                     |                      |     0.0 |            |           |          |      |                  |              |                   |              |
| C9         |                          |            | GND                          | GND         |             |         |            |      |                     |                      |     0.0 |            |           |          |      |                  |              |                   |              |
| C10        | tx_o                     | High Range | IO_L2N_T0_D03_14             | OUTPUT      | LVCMOS33    |      14 |         12 | SLOW |                     |            FP_VTT_50 |         | FIXED      |           |          |      | NONE             |              |                   |              |
| C11        |                          | High Range | IO_L6P_T0_FCS_B_14           | User IO     |             |      14 |            |      |                     |                      |         |            |           |          |      |                  |              |                   |              |
| C12        |                          | High Range | IO_L6N_T0_D08_VREF_14        | User IO     |             |      14 |            |      |                     |                      |         |            |           |          |      |                  |              |                   |              |
| C13        |                          |            | GND                          | GND         |             |         |            |      |                     |                      |     0.0 |            |           |          |      |                  |              |                   |              |
| C14        | init_led_o               | High Range | IO_L11N_T1_SRCC_14           | OUTPUT      | LVCMOS33    |      14 |         12 | SLOW |                     |            FP_VTT_50 |         | FIXED      |           |          |      | NONE             |              |                   |              |
| D1         |                          | High Range | IO_L11P_T1_SRCC_34           | User IO     |             |      34 |            |      |                     |                      |         |            |           |          |      |                  |              |                   |              |
| D2         | charge_direction_upper_o | High Range | IO_L10N_T1_34                | OUTPUT      | LVCMOS33    |      34 |         12 | SLOW |                     |            FP_VTT_50 |         | FIXED      |           |          |      | NONE             |              |                   |              |
| D3         |                          | High Range | IO_L1P_T0_34                 | User IO     |             |      34 |            |      |                     |                      |         |            |           |          |      |                  |              |                   |              |
| D4         | charge_deactive_lower_o  | High Range | IO_L7N_T1_34                 | OUTPUT      | LVCMOS33    |      34 |         12 | SLOW |                     |            FP_VTT_50 |         | FIXED      |           |          |      | NONE             |              |                   |              |
| D5         |                          |            | GND                          | GND         |             |         |            |      |                     |                      |     0.0 |            |           |          |      |                  |              |                   |              |
| D6         |                          |            | VCCINT                       | VCCINT      |             |         |            |      |                     |                      |         |            |           |          |      |                  |              |                   |              |
| D7         |                          |            | GND                          | GND         |             |         |            |      |                     |                      |     0.0 |            |           |          |      |                  |              |                   |              |
| D8         |                          |            | VCCINT                       | VCCINT      |             |         |            |      |                     |                      |         |            |           |          |      |                  |              |                   |              |
| D9         |                          |            | GND                          | GND         |             |         |            |      |                     |                      |     0.0 |            |           |          |      |                  |              |                   |              |
| D10        |                          | High Range | IO_L2P_T0_D02_14             | User IO     |             |      14 |            |      |                     |                      |         |            |           |          |      |                  |              |                   |              |
| D11        |                          |            | GND                          | GND         |             |         |            |      |                     |                      |     0.0 |            |           |          |      |                  |              |                   |              |
| D12        | enable_ref_o             | High Range | IO_L8P_T1_D11_14             | OUTPUT      | LVCMOS33    |      14 |         12 | SLOW |                     |            FP_VTT_50 |         | FIXED      |           |          |      | NONE             |              |                   |              |
| D13        |                          | High Range | IO_L8N_T1_D12_14             | User IO     |             |      14 |            |      |                     |                      |         |            |           |          |      |                  |              |                   |              |
| D14        | overflow_led_o           | High Range | IO_L11P_T1_SRCC_14           | OUTPUT      | LVCMOS33    |      14 |         12 | SLOW |                     |            FP_VTT_50 |         | FIXED      |           |          |      | NONE             |              |                   |              |
| E1         |                          |            | GND                          | GND         |             |         |            |      |                     |                      |     0.0 |            |           |          |      |                  |              |                   |              |
| E2         |                          | High Range | IO_L10P_T1_34                | User IO     |             |      34 |            |      |                     |                      |         |            |           |          |      |                  |              |                   |              |
| E3         |                          |            | GND                          | GND         |             |         |            |      |                     |                      |     0.0 |            |           |          |      |                  |              |                   |              |
| E4         |                          | High Range | IO_L7P_T1_34                 | User IO     |             |      34 |            |      |                     |                      |         |            |           |          |      |                  |              |                   |              |
| E5         |                          |            | VCCBRAM                      | VCCBRAM     |             |         |            |      |                     |                      |         |            |           |          |      |                  |              |                   |              |
| E6         |                          |            | GND                          | GND         |             |         |            |      |                     |                      |     0.0 |            |           |          |      |                  |              |                   |              |
| E7         |                          |            | VCCINT                       | VCCINT      |             |         |            |      |                     |                      |         |            |           |          |      |                  |              |                   |              |
| E8         |                          |            | GND                          | GND         |             |         |            |      |                     |                      |     0.0 |            |           |          |      |                  |              |                   |              |
| E9         |                          |            | VCCINT                       | VCCINT      |             |         |            |      |                     |                      |         |            |           |          |      |                  |              |                   |              |
| E10        |                          |            | GND                          | GND         |             |         |            |      |                     |                      |     0.0 |            |           |          |      |                  |              |                   |              |
| E11        |                          | High Range | IO_0_14                      | User IO     |             |      14 |            |      |                     |                      |         |            |           |          |      |                  |              |                   |              |
| E12        |                          | High Range | IO_L7N_T1_D10_14             | User IO     |             |      14 |            |      |                     |                      |         |            |           |          |      |                  |              |                   |              |
| E13        |                          | High Range | IO_L10N_T1_D15_14            | User IO     |             |      14 |            |      |                     |                      |         |            |           |          |      |                  |              |                   |              |
| E14        |                          |            | GND                          | GND         |             |         |            |      |                     |                      |     0.0 |            |           |          |      |                  |              |                   |              |
| F1         | charge_deactive_upper_o  | High Range | IO_L9N_T1_DQS_34             | OUTPUT      | LVCMOS33    |      34 |         12 | SLOW |                     |            FP_VTT_50 |         | FIXED      |           |          |      | NONE             |              |                   |              |
| F2         |                          | High Range | IO_L8N_T1_34                 | User IO     |             |      34 |            |      |                     |                      |         |            |           |          |      |                  |              |                   |              |
| F3         | zero_switch_in_upper_o   | High Range | IO_L8P_T1_34                 | OUTPUT      | LVCMOS33    |      34 |         12 | SLOW |                     |            FP_VTT_50 |         | FIXED      |           |          |      | NONE             |              |                   |              |
| F4         | zero_switch_en_upper_o   | High Range | IO_L12N_T1_MRCC_34           | OUTPUT      | LVCMOS33    |      34 |         12 | SLOW |                     |            FP_VTT_50 |         | FIXED      |           |          |      | NONE             |              |                   |              |
| F5         |                          |            | GND                          | GND         |             |         |            |      |                     |                      |     0.0 |            |           |          |      |                  |              |                   |              |
| F6         |                          |            | VCCINT                       | VCCINT      |             |         |            |      |                     |                      |         |            |           |          |      |                  |              |                   |              |
| F7         |                          | Dedicated  | GNDADC_0                     | XADC        |             |       0 |            |      |                     |                      |         |            |           |          |      |                  |              |                   |              |
| F8         |                          | Dedicated  | VCCADC_0                     | XADC        |             |       0 |            |      |                     |                      |         |            |           |          |      |                  |              |                   |              |
| F9         |                          |            | GND                          | GND         |             |         |            |      |                     |                      |     0.0 |            |           |          |      |                  |              |                   |              |
| F10        |                          |            | VCCAUX                       | VCCAUX      |             |         |            |      |                     |                      |    1.80 |            |           |          |      |                  |              |                   |              |
| F11        |                          | High Range | IO_L12N_T1_MRCC_14           | User IO     |             |      14 |            |      |                     |                      |         |            |           |          |      |                  |              |                   |              |
| F12        |                          | High Range | IO_L7P_T1_D09_14             | User IO     |             |      14 |            |      |                     |                      |         |            |           |          |      |                  |              |                   |              |
| F13        |                          | High Range | IO_L10P_T1_D14_14            | User IO     |             |      14 |            |      |                     |                      |         |            |           |          |      |                  |              |                   |              |
| F14        | reset_n_i                | High Range | IO_L9N_T1_DQS_D13_14         | INPUT       | LVCMOS33    |      14 |            |      |                     |                 NONE |         | FIXED      |           |          |      | NONE             |              |                   |              |
| G1         |                          | High Range | IO_L9P_T1_DQS_34             | User IO     |             |      34 |            |      |                     |                      |         |            |           |          |      |                  |              |                   |              |
| G2         |                          | High Range | VCCO_34                      | VCCO        |             |      34 |            |      |                     |                      |    3.30 |            |           |          |      |                  |              |                   |              |
| G3         |                          |            | GND                          | GND         |             |         |            |      |                     |                      |     0.0 |            |           |          |      |                  |              |                   |              |
| G4         |                          | High Range | IO_L12P_T1_MRCC_34           | User IO     |             |      34 |            |      |                     |                      |         |            |           |          |      |                  |              |                   |              |
| G5         |                          |            | VCCBRAM                      | VCCBRAM     |             |         |            |      |                     |                      |         |            |           |          |      |                  |              |                   |              |
| G6         |                          |            | GND                          | GND         |             |         |            |      |                     |                      |     0.0 |            |           |          |      |                  |              |                   |              |
| G7         |                          | Dedicated  | VREFN_0                      | XADC        |             |       0 |            |      |                     |                      |         |            |           |          |      |                  |              |                   |              |
| G8         |                          | Dedicated  | VP_0                         | XADC        |             |       0 |            |      |                     |                      |         |            |           |          |      |                  |              |                   |              |
| G9         |                          |            | VCCINT                       | VCCINT      |             |         |            |      |                     |                      |         |            |           |          |      |                  |              |                   |              |
| G10        |                          |            | GND                          | GND         |             |         |            |      |                     |                      |     0.0 |            |           |          |      |                  |              |                   |              |
| G11        |                          | High Range | IO_L12P_T1_MRCC_14           | User IO     |             |      14 |            |      |                     |                      |         |            |           |          |      |                  |              |                   |              |
| G12        |                          |            | GND                          | GND         |             |         |            |      |                     |                      |     0.0 |            |           |          |      |                  |              |                   |              |
| G13        |                          | High Range | VCCO_14                      | VCCO        |             |      14 |            |      |                     |                      |    3.30 |            |           |          |      |                  |              |                   |              |
| G14        |                          | High Range | IO_L9P_T1_DQS_14             | User IO     |             |      14 |            |      |                     |                      |         |            |           |          |      |                  |              |                   |              |
| H1         |                          | High Range | IO_L14N_T2_SRCC_34           | User IO     |             |      34 |            |      |                     |                      |         |            |           |          |      |                  |              |                   |              |
| H2         |                          | High Range | IO_L14P_T2_SRCC_34           | User IO     |             |      34 |            |      |                     |                      |         |            |           |          |      |                  |              |                   |              |
| H3         | zero_switch_in_lower_o   | High Range | IO_L13N_T2_MRCC_34           | OUTPUT      | LVCMOS33    |      34 |         12 | SLOW |                     |            FP_VTT_50 |         | FIXED      |           |          |      | NONE             |              |                   |              |
| H4         |                          | High Range | IO_L13P_T2_MRCC_34           | User IO     |             |      34 |            |      |                     |                      |         |            |           |          |      |                  |              |                   |              |
| H5         |                          |            | GND                          | GND         |             |         |            |      |                     |                      |     0.0 |            |           |          |      |                  |              |                   |              |
| H6         |                          |            | VCCINT                       | VCCINT      |             |         |            |      |                     |                      |         |            |           |          |      |                  |              |                   |              |
| H7         |                          | Dedicated  | VN_0                         | XADC        |             |       0 |            |      |                     |                      |         |            |           |          |      |                  |              |                   |              |
| H8         |                          | Dedicated  | VREFP_0                      | XADC        |             |       0 |            |      |                     |                      |         |            |           |          |      |                  |              |                   |              |
| H9         |                          |            | GND                          | GND         |             |         |            |      |                     |                      |     0.0 |            |           |          |      |                  |              |                   |              |
| H10        |                          |            | VCCAUX                       | VCCAUX      |             |         |            |      |                     |                      |    1.80 |            |           |          |      |                  |              |                   |              |
| H11        |                          | High Range | IO_L13P_T2_MRCC_14           | User IO     |             |      14 |            |      |                     |                      |         |            |           |          |      |                  |              |                   |              |
| H12        |                          | High Range | IO_L13N_T2_MRCC_14           | User IO     |             |      14 |            |      |                     |                      |         |            |           |          |      |                  |              |                   |              |
| H13        |                          | High Range | IO_L14P_T2_SRCC_14           | User IO     |             |      14 |            |      |                     |                      |         |            |           |          |      |                  |              |                   |              |
| H14        |                          | High Range | IO_L14N_T2_SRCC_14           | User IO     |             |      14 |            |      |                     |                      |         |            |           |          |      |                  |              |                   |              |
| J1         |                          | High Range | IO_L15N_T2_DQS_34            | User IO     |             |      34 |            |      |                     |                      |         |            |           |          |      |                  |              |                   |              |
| J2         |                          | High Range | IO_L15P_T2_DQS_34            | User IO     |             |      34 |            |      |                     |                      |         |            |           |          |      |                  |              |                   |              |
| J3         | zero_switch_en_lower_o   | High Range | IO_L17N_T2_34                | OUTPUT      | LVCMOS33    |      34 |         12 | SLOW |                     |            FP_VTT_50 |         | FIXED      |           |          |      | NONE             |              |                   |              |
| J4         |                          | High Range | IO_L17P_T2_34                | User IO     |             |      34 |            |      |                     |                      |         |            |           |          |      |                  |              |                   |              |
| J5         |                          |            | VCCBRAM                      | VCCBRAM     |             |         |            |      |                     |                      |         |            |           |          |      |                  |              |                   |              |
| J6         |                          |            | GND                          | GND         |             |         |            |      |                     |                      |     0.0 |            |           |          |      |                  |              |                   |              |
| J7         |                          | Dedicated  | DXN_0                        | Temp Sensor |             |       0 |            |      |                     |                      |         |            |           |          |      |                  |              |                   |              |
| J8         |                          | Dedicated  | DXP_0                        | Temp Sensor |             |       0 |            |      |                     |                      |         |            |           |          |      |                  |              |                   |              |
| J9         |                          |            | VCCINT                       | VCCINT      |             |         |            |      |                     |                      |         |            |           |          |      |                  |              |                   |              |
| J10        |                          |            | GND                          | GND         |             |         |            |      |                     |                      |     0.0 |            |           |          |      |                  |              |                   |              |
| J11        |                          | High Range | IO_L17P_T2_D30_14            | User IO     |             |      14 |            |      |                     |                      |         |            |           |          |      |                  |              |                   |              |
| J12        |                          | High Range | IO_L17N_T2_D29_14            | User IO     |             |      14 |            |      |                     |                      |         |            |           |          |      |                  |              |                   |              |
| J13        |                          | High Range | IO_L18P_T2_D28_14            | User IO     |             |      14 |            |      |                     |                      |         |            |           |          |      |                  |              |                   |              |
| J14        |                          | High Range | IO_L18N_T2_D27_14            | User IO     |             |      14 |            |      |                     |                      |         |            |           |          |      |                  |              |                   |              |
| K1         |                          |            | GND                          | GND         |             |         |            |      |                     |                      |     0.0 |            |           |          |      |                  |              |                   |              |
| K2         |                          | High Range | VCCO_34                      | VCCO        |             |      34 |            |      |                     |                      |    3.30 |            |           |          |      |                  |              |                   |              |
| K3         | adaptive_mode_i          | High Range | IO_L16N_T2_34                | INPUT       | LVCMOS33    |      34 |            |      |                     |                 NONE |         | FIXED      |           |          |      | NONE             |              |                   |              |
| K4         |                          | High Range | IO_L16P_T2_34                | User IO     |             |      34 |            |      |                     |                      |         |            |           |          |      |                  |              |                   |              |
| K5         |                          |            | GND                          | GND         |             |         |            |      |                     |                      |     0.0 |            |           |          |      |                  |              |                   |              |
| K6         |                          |            | VCCINT                       | VCCINT      |             |         |            |      |                     |                      |         |            |           |          |      |                  |              |                   |              |
| K7         |                          |            | GND                          | GND         |             |         |            |      |                     |                      |     0.0 |            |           |          |      |                  |              |                   |              |
| K8         |                          |            | VCCINT                       | VCCINT      |             |         |            |      |                     |                      |         |            |           |          |      |                  |              |                   |              |
| K9         |                          |            | GND                          | GND         |             |         |            |      |                     |                      |     0.0 |            |           |          |      |                  |              |                   |              |
| K10        |                          |            | VCCAUX                       | VCCAUX      |             |         |            |      |                     |                      |    1.80 |            |           |          |      |                  |              |                   |              |
| K11        |                          | High Range | IO_L19P_T3_D26_14            | User IO     |             |      14 |            |      |                     |                      |         |            |           |          |      |                  |              |                   |              |
| K12        |                          | High Range | IO_L19N_T3_D25_VREF_14       | User IO     |             |      14 |            |      |                     |                      |         |            |           |          |      |                  |              |                   |              |
| K13        |                          | High Range | VCCO_14                      | VCCO        |             |      14 |            |      |                     |                      |    3.30 |            |           |          |      |                  |              |                   |              |
| K14        |                          |            | GND                          | GND         |             |         |            |      |                     |                      |     0.0 |            |           |          |      |                  |              |                   |              |
| L1         |                          | High Range | IO_L18N_T2_34                | User IO     |             |      34 |            |      |                     |                      |         |            |           |          |      |                  |              |                   |              |
| L2         | init_btn_i               | High Range | IO_L22N_T3_34                | INPUT       | LVCMOS33    |      34 |            |      |                     |                 NONE |         | FIXED      |           |          |      | NONE             |              |                   |              |
| L3         |                          | High Range | IO_L22P_T3_34                | User IO     |             |      34 |            |      |                     |                      |         |            |           |          |      |                  |              |                   |              |
| L4         |                          |            | GND                          | GND         |             |         |            |      |                     |                      |     0.0 |            |           |          |      |                  |              |                   |              |
| L5         | clock_i                  | High Range | IO_25_34                     | INPUT       | LVCMOS33    |      34 |            |      |                     |                 NONE |         | FIXED      |           |          |      | NONE             |              |                   |              |
| L6         |                          |            | GND                          | GND         |             |         |            |      |                     |                      |     0.0 |            |           |          |      |                  |              |                   |              |
| L7         |                          | Dedicated  | PROGRAM_B_0                  | Config      |             |       0 |            |      |                     |                      |         |            |           |          |      |                  |              |                   |              |
| L8         |                          |            | GND                          | GND         |             |         |            |      |                     |                      |     0.0 |            |           |          |      |                  |              |                   |              |
| L9         |                          |            | VCCAUX                       | VCCAUX      |             |         |            |      |                     |                      |    1.80 |            |           |          |      |                  |              |                   |              |
| L10        |                          |            | GND                          | GND         |             |         |            |      |                     |                      |     0.0 |            |           |          |      |                  |              |                   |              |
| L11        |                          |            | GND                          | GND         |             |         |            |      |                     |                      |     0.0 |            |           |          |      |                  |              |                   |              |
| L12        |                          | High Range | IO_L16P_T2_CSI_B_14          | User IO     |             |      14 |            |      |                     |                      |         |            |           |          |      |                  |              |                   |              |
| L13        |                          | High Range | IO_L16N_T2_D31_14            | User IO     |             |      14 |            |      |                     |                      |         |            |           |          |      |                  |              |                   |              |
| L14        |                          | High Range | IO_L15N_T2_DQS_DOUT_CSO_B_14 | User IO     |             |      14 |            |      |                     |                      |         |            |           |          |      |                  |              |                   |              |
| M1         |                          | High Range | IO_L18P_T2_34                | User IO     |             |      34 |            |      |                     |                      |         |            |           |          |      |                  |              |                   |              |
| M2         | debug_btn_i              | High Range | IO_L19N_T3_VREF_34           | INPUT       | LVCMOS33    |      34 |            |      |                     |                 NONE |         | FIXED      |           |          |      | NONE             |              |                   |              |
| M3         |                          | High Range | IO_L19P_T3_34                | User IO     |             |      34 |            |      |                     |                      |         |            |           |          |      |                  |              |                   |              |
| M4         |                          | High Range | IO_L23N_T3_34                | User IO     |             |      34 |            |      |                     |                      |         |            |           |          |      |                  |              |                   |              |
| M5         |                          | High Range | IO_L23P_T3_34                | User IO     |             |      34 |            |      |                     |                      |         |            |           |          |      |                  |              |                   |              |
| M6         |                          | Dedicated  | TMS_0                        | Config      |             |       0 |            |      |                     |                      |         |            |           |          |      |                  |              |                   |              |
| M7         |                          | Dedicated  | M0_0                         | Config      |             |       0 |            |      |                     |                      |         |            |           |          |      |                  |              |                   |              |
| M8         |                          | Dedicated  | M1_0                         | Config      |             |       0 |            |      |                     |                      |         |            |           |          |      |                  |              |                   |              |
| M9         |                          | Dedicated  | M2_0                         | Config      |             |       0 |            |      |                     |                      |         |            |           |          |      |                  |              |                   |              |
| M10        |                          | High Range | IO_25_14                     | User IO     |             |      14 |            |      |                     |                      |         |            |           |          |      |                  |              |                   |              |
| M11        |                          | High Range | IO_L20P_T3_D24_14            | User IO     |             |      14 |            |      |                     |                      |         |            |           |          |      |                  |              |                   |              |
| M12        |                          | High Range | IO_L20N_T3_D23_14            | User IO     |             |      14 |            |      |                     |                      |         |            |           |          |      |                  |              |                   |              |
| M13        |                          | High Range | IO_L15P_T2_DQS_RDWR_B_14     | User IO     |             |      14 |            |      |                     |                      |         |            |           |          |      |                  |              |                   |              |
| M14        |                          | High Range | IO_L21N_T3_DQS_D22_14        | User IO     |             |      14 |            |      |                     |                      |         |            |           |          |      |                  |              |                   |              |
| N1         |                          | High Range | IO_L20N_T3_34                | User IO     |             |      34 |            |      |                     |                      |         |            |           |          |      |                  |              |                   |              |
| N2         |                          | High Range | VCCO_34                      | VCCO        |             |      34 |            |      |                     |                      |    3.30 |            |           |          |      |                  |              |                   |              |
| N3         |                          |            | GND                          | GND         |             |         |            |      |                     |                      |     0.0 |            |           |          |      |                  |              |                   |              |
| N4         |                          | High Range | IO_L24N_T3_34                | User IO     |             |      34 |            |      |                     |                      |         |            |           |          |      |                  |              |                   |              |
| N5         |                          |            | GND                          | GND         |             |         |            |      |                     |                      |     0.0 |            |           |          |      |                  |              |                   |              |
| N6         |                          | Dedicated  | VCCO_0                       | VCCO        |             |       0 |            |      |                     |                      |    3.30 |            |           |          |      |                  |              |                   |              |
| N7         |                          | Dedicated  | CFGBVS_0                     | Config      |             |       0 |            |      |                     |                      |    3.30 |            |           |          |      |                  |              |                   |              |
| N8         |                          | Dedicated  | VCCO_0                       | VCCO        |             |       0 |            |      |                     |                      |    3.30 |            |           |          |      |                  |              |                   |              |
| N9         |                          |            | GND                          | GND         |             |         |            |      |                     |                      |     0.0 |            |           |          |      |                  |              |                   |              |
| N10        |                          | High Range | IO_L23P_T3_D19_14            | User IO     |             |      14 |            |      |                     |                      |         |            |           |          |      |                  |              |                   |              |
| N11        |                          | High Range | IO_L23N_T3_D18_14            | User IO     |             |      14 |            |      |                     |                      |         |            |           |          |      |                  |              |                   |              |
| N12        |                          |            | GND                          | GND         |             |         |            |      |                     |                      |     0.0 |            |           |          |      |                  |              |                   |              |
| N13        |                          | High Range | VCCO_14                      | VCCO        |             |      14 |            |      |                     |                      |    3.30 |            |           |          |      |                  |              |                   |              |
| N14        |                          | High Range | IO_L21P_T3_DQS_14            | User IO     |             |      14 |            |      |                     |                      |         |            |           |          |      |                  |              |                   |              |
| P1         |                          |            | GND                          | GND         |             |         |            |      |                     |                      |     0.0 |            |           |          |      |                  |              |                   |              |
| P2         |                          | High Range | IO_L20P_T3_34                | User IO     |             |      34 |            |      |                     |                      |         |            |           |          |      |                  |              |                   |              |
| P3         |                          | High Range | IO_L21N_T3_DQS_34            | User IO     |             |      34 |            |      |                     |                      |         |            |           |          |      |                  |              |                   |              |
| P4         |                          | High Range | IO_L21P_T3_DQS_34            | User IO     |             |      34 |            |      |                     |                      |         |            |           |          |      |                  |              |                   |              |
| P5         |                          | High Range | IO_L24P_T3_34                | User IO     |             |      34 |            |      |                     |                      |         |            |           |          |      |                  |              |                   |              |
| P6         |                          | Dedicated  | TDO_0                        | Config      |             |       0 |            |      |                     |                      |         |            |           |          |      |                  |              |                   |              |
| P7         |                          | Dedicated  | TDI_0                        | Config      |             |       0 |            |      |                     |                      |         |            |           |          |      |                  |              |                   |              |
| P8         |                          | Dedicated  | INIT_B_0                     | Config      |             |       0 |            |      |                     |                      |         |            |           |          |      |                  |              |                   |              |
| P9         |                          | Dedicated  | DONE_0                       | Config      |             |       0 |            |      |                     |                      |         |            |           |          |      |                  |              |                   |              |
| P10        |                          | High Range | IO_L24P_T3_D17_14            | User IO     |             |      14 |            |      |                     |                      |         |            |           |          |      |                  |              |                   |              |
| P11        |                          | High Range | IO_L24N_T3_D16_14            | User IO     |             |      14 |            |      |                     |                      |         |            |           |          |      |                  |              |                   |              |
| P12        |                          | High Range | IO_L22P_T3_D21_14            | User IO     |             |      14 |            |      |                     |                      |         |            |           |          |      |                  |              |                   |              |
| P13        |                          | High Range | IO_L22N_T3_D20_14            | User IO     |             |      14 |            |      |                     |                      |         |            |           |          |      |                  |              |                   |              |
| P14        |                          |            | GND                          | GND         |             |         |            |      |                     |                      |     0.0 |            |           |          |      |                  |              |                   |              |
+------------+--------------------------+------------+------------------------------+-------------+-------------+---------+------------+------+---------------------+----------------------+---------+------------+-----------+----------+------+------------------+--------------+-------------------+--------------+
* Default value

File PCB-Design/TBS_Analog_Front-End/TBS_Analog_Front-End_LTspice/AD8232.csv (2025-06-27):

f | gain | phase
1.00000000000000e-02 | -4.91979301739025e+00 | 9.52974994880428e+01
1.00230293249304e-02 | -4.89949304786720e+00 | 9.53095355164148e+01
1.00461116848415e-02 | -4.87919161431311e+00 | 9.53215980377792e+01
1.00692472018692e-02 | -4.85888871022008e+00 | 9.53336871046377e+01
1.00924359984308e-02 | -4.83858432859826e+00 | 9.53458027691747e+01
1.01156781972255e-02 | -4.81827846302111e+00 | 9.53579450840463e+01
1.01389739212350e-02 | -4.79797110691278e+00 | 9.53701141016617e+01
1.01623232937243e-02 | -4.77766225365202e+00 | 9.53823098747866e+01
1.01857264382422e-02 | -4.75735189641630e+00 | 9.53945324560011e+01
1.02091834786220e-02 | -4.73704002856543e+00 | 9.54067818978926e+01
1.02326945389823e-02 | -4.71672664325065e+00 | 9.54190582535451e+01
1.02562597437275e-02 | -4.69641173365066e+00 | 9.54313615754911e+01
1.02798792175484e-02 | -4.67609529317351e+00 | 9.54436919168305e+01
1.03035530854230e-02 | -4.65577731470595e+00 | 9.54560493304650e+01
1.03272814726172e-02 | -4.63545779158937e+00 | 9.54684338694511e+01
1.03510645046852e-02 | -4.61513671675295e+00 | 9.54808455868744e+01
1.03749023074706e-02 | -4.59481408336671e+00 | 9.54932845357731e+01
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

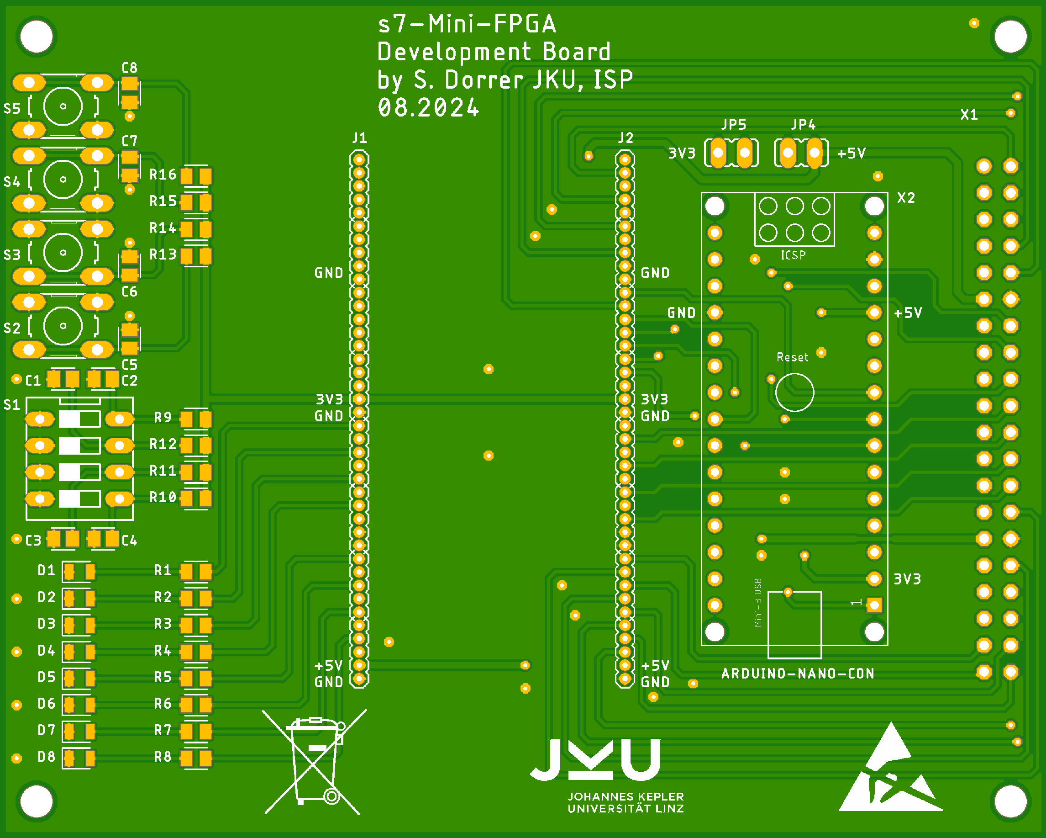
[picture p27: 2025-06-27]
PCB-Design/s7-Mini-FPGA Development Board/s7-Mini-FPGA-Development-Board_Pics/s7-Mini-FPGA Development Board_Top.png

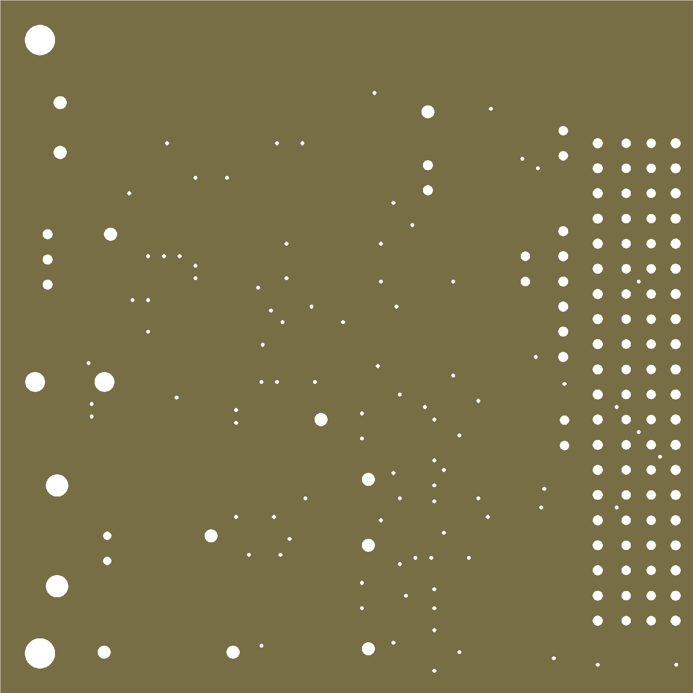
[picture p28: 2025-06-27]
PCB-Design/TBS_Analog_Front-End/TBS_Analog_Front-End_Pics/TBS_Analog_Front-End_Drills_2D.png

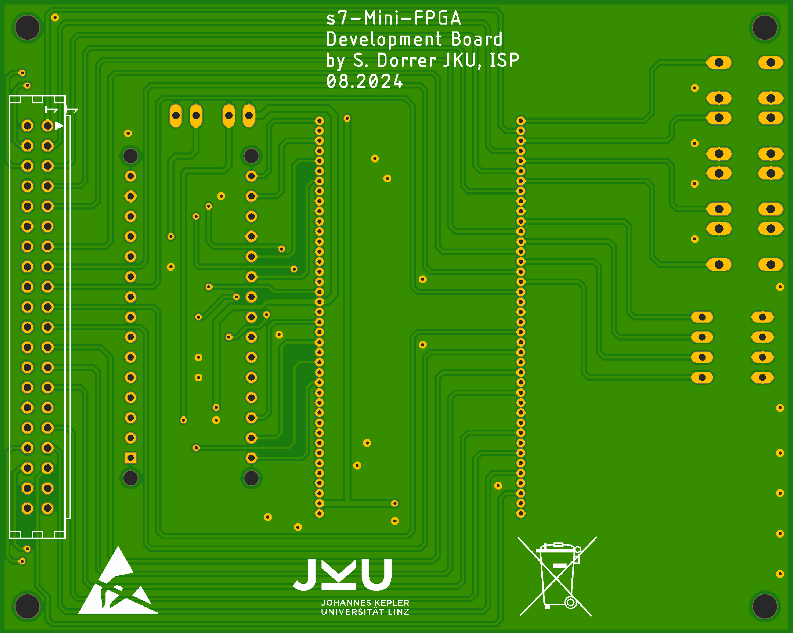
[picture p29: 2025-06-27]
PCB-Design/s7-Mini-FPGA Development Board/s7-Mini-FPGA-Development-Board_Pics/s7-Mini-FPGA Development Board_Bottom.png

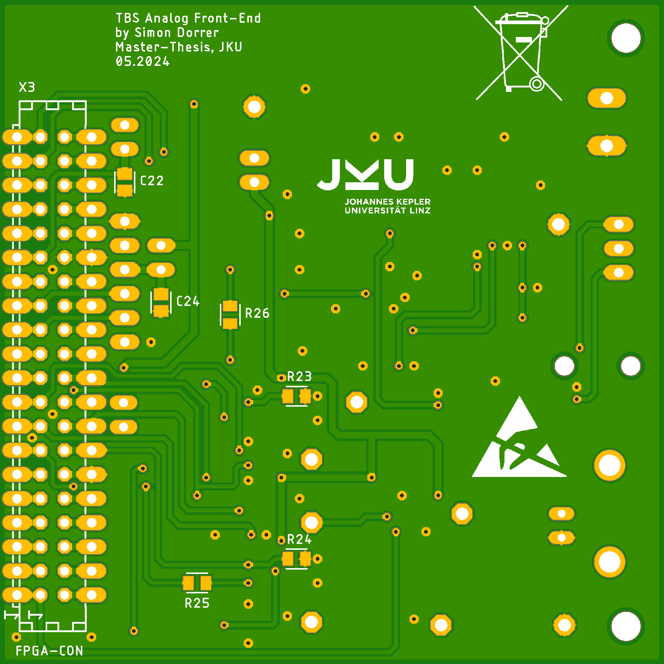
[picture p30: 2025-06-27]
PCB-Design/TBS_Analog_Front-End/TBS_Analog_Front-End_Pics/TBS_Analog_Front-End_BOTTOM_2D.png

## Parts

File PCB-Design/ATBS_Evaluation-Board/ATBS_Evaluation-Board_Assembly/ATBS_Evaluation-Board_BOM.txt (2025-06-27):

Partlist exported from Fusion Hub: EuroSkills & WorldSkills - Training AT   Project: JKU  Board: ATBS_Evaluation-Board v4 at 25.03.2025 08:32

Qty Value                Device                   Package              Parts                                                                                                         Description                                     CATEGORY     COLOR COPYRIGHT                                                CURRENT_RATING DATASHEET DESCRIPTION                  MANUFACTURER       MANUFACTURER_PART_NUMBER MF MFR_NAME               MPN        OC_FARNELL OC_NEWARK OPERATING_TEMP OPERATING_TEMPERATURE PACKAGE_SIZE PACKAGE_TYPE PART_STATUS PITCH           POPULARITY PROD_ID    RATING ROHS ROHS_COMPLIANT SERIES SF_ID     SPICEPREFIX SUB-CATEGORY      SUBCATEGORY       THERMALLOSS TOLERANCE TP_SIGNAL_NAME TYPE                                                     VALUE     VOLTAGE_RATING
2                        10-XX                    B3F-10XX             S1, S3                                                                                                        OMRON SWITCH                                                                                                                                                                                                                                            B3F-1000   176432     36M3542                                                                                              72                                                                                                                                                                                                                                      
5   100nF                C_CHIP-0603(1608-METRIC) CAPC1608X85          C32, C34, C36, C37, C39                                                                                       Capacitor - Generic                             Capacitor                                                                                                                                                                                                                                                                                                                                                                                                                                                                                                                                                                  
20  100nF                C_CHIP-0805(2012-METRIC) CAPC2012X110         C1, C2, C3, C4, C6, C15, C16, C17, C18, C21, C22, C23, C24, C25, C27, C28, C29, C30, C35, C38                 Capacitor - Generic                             Capacitor                                                                                                                                                                                                                                                                                                                                                                                                                                                                                                                                                                  
23  10k                  R_CHIP-0805(2012-METRIC) RESC2012X65          R1, R2, R7, R8, R13, R14, R17, R18, R19, R20, R21, R23, R24, R25, R26, R27, R28, R29, R30, R31, R32, R33, R34 Resistor Fixed - Generic                        Resistor                                                                                                                                                                                                                                                                                                                                                                                                         Fixed                                                                                                                                                     
7   10nF                 C_CHIP-0805(2012-METRIC) CAPC2012X110         C7, C8, C9, C10, C11, C12, C31                                                                                Capacitor - Generic                             Capacitor                                                                                                                                                                                                                                                                                                                                                                                                                                                                                                                                                                  
1   10uF                 C_CHIP-0805(2012-METRIC) CAPC2012X110         C40                                                                                                           Capacitor - Generic                             Capacitor                                                                                                                                                                                                                                                                                                                                                                                                                                                                                                                                                                  
2   1k                   R_CHIP-0805(2012-METRIC) RESC2012X65          R35, R36                                                                                                      Resistor Fixed - Generic                        Resistor                                                                                                                                                                                                                                                                                                                                                                                                         Fixed                                                                                                                                                     
1   22uF                 CPOL-EUSMCD              SMC_D                C5                                                                                                            POLARIZED CAPACITOR, European symbol                                                                                                                                                                                                                                                                                                                                               0                                                                 C                                                                                                                                                                     
5   470R                 R_CHIP-0805(2012-METRIC) RESC2012X65          R15, R16, R22, R37, R38                                                                                       Resistor Fixed - Generic                        Resistor                                                                                                                                                                                                                                                                                                                                                                                                         Fixed                                                                                                                                                     
1   470nF                C_CHIP-0805(2012-METRIC) CAPC2012X110         C33                                                                                                           Capacitor - Generic                             Capacitor                                                                                                                                                                                                                                                                                                                                                                                                                                                                                                                                                                  
1   5V...12V             AK500/2                  AK500/2              X1                                                                                                            CONNECTOR                                                                                                                                                                                                                                                          unknown    unknown                                                                                              14                                                                                                                                                                                                                                      
1   AMP_I                PINHD-1X2                1X02                 JP1                                                                                                           PIN HEADER                                      Headers                                                                                              Header-Straight-2 Position                                                                                                                                                           THT                      0.100" (2.54mm)                                                                                                 Headers-Male Pins                                      Board to Board or Cable-Unshrouded-Through Hole-Straight                         
1   AMP_U                PINHD-1X2                1X02                 JP5                                                                                                           PIN HEADER                                      Headers                                                                                              Header-Straight-2 Position                                                                                                                                                           THT                      0.100" (2.54mm)                                                                                                 Headers-Male Pins                                      Board to Board or Cable-Unshrouded-Through Hole-Straight                         
1   ATBS-ADC             ATBS-ADC                 ATBS-ADC             U9                                                                                                                                                                                                                                                                                                                                                                                                                                                                                                                                                                                                                                                                                                                                       
1   AUDIO_JACK_3.5MM_SMD AUDIO_JACK_3.5MM_SMD     AUDIO-JACK-3.5MM-SMD X4                                                                                                            Audio Jack                                                                                                                                                                                                                                                                                                                                                                                    CONN-10353                                                                                                                                                                                                                   
13  BAT54S               BAT54S                   SOT23                D1, D2, D3, D4, D8, D9, D10, D11, D12, D13, D14, D15, D16                                                     Schottky Diodes                                                                                                                                                                                                                                                                                                                                                                    6                                                                                                                                                                                                                                       
1   BLUE                 CHIP-FLAT-B_0805         LEDC2012X110N_FLAT-B D5                                                                                                                                                            LED          BLUE                                                                                    CHIP LED FLAT                                                                                                                                                                                                                                                                                               CHIP                                                                     FLAT_TOP                                                 LED_BLUE                
1   CLOCK SELECT         PINHD-1X3                1X03                 JP15                                                                                                          PIN HEADER                                                                                                                                                                                                                                                                                                                                                                         92                                                                                                                                                                                                                                      
1   COMP_I               PINHD-1X2                1X02                 JP2                                                                                                           PIN HEADER                                      Headers                                                                                              Header-Straight-2 Position                                                                                                                                                           THT                      0.100" (2.54mm)                                                                                                 Headers-Male Pins                                      Board to Board or Cable-Unshrouded-Through Hole-Straight                         
1   COMP_U               PINHD-1X2                1X02                 JP6                                                                                                           PIN HEADER                                      Headers                                                                                              Header-Straight-2 Position                                                                                                                                                           THT                      0.100" (2.54mm)                                                                                                 Headers-Male Pins                                      Board to Board or Cable-Unshrouded-Through Hole-Straight                         
1   DAC_I                PINHD-1X2                1X02                 JP3                                                                                                           PIN HEADER                                      Headers                                                                                              Header-Straight-2 Position                                                                                                                                                           THT                      0.100" (2.54mm)                                                                                                 Headers-Male Pins                                      Board to Board or Cable-Unshrouded-Through Hole-Straight                         
1   DAC_U                PINHD-1X2                1X02                 JP7                                                                                                           PIN HEADER                                      Headers                                                                                              Header-Straight-2 Position                                                                                                                                                           THT                      0.100" (2.54mm)                                                                                                 Headers-Male Pins                                      Board to Board or Cable-Unshrouded-Through Hole-Straight                         
1   DIG_I                PINHD-1X2                1X02                 JP4                                                                                                           PIN HEADER                                      Headers                                                                                              Header-Straight-2 Position                                                                                                                                                           THT                      0.100" (2.54mm)                                                                                                 Headers-Male Pins                                      Board to Board or Cable-Unshrouded-Through Hole-Straight                         
1   DIG_U                PINHD-1X2                1X02                 JP8                                                                                                           PIN HEADER                                      Headers                                                                                              Header-Straight-2 Position                                                                                                                                                           THT                      0.100" (2.54mm)                                                                                                 Headers-Male Pins                                      Board to Board or Cable-Unshrouded-Through Hole-Straight                         
5   DNP                  C_CHIP-0805(2012-METRIC) CAPC2012X110         C13, C14, C19, C20, C26                                                                                       Capacitor - Generic                             Capacitor                                                                                                                                                                                                                                                                                                                                                                                                                                                                                                                                                                  
1   DNP                  L_CHIP-0805(2012-METRIC) INDC2009X120         L2                                                                                                            Inductor Fixed - Generic                        Inductor                                                                                                                                                                                                                                                                                                                                                                                                         Fixed                                                                                                                                                     
1   DNP                  L_MOLDED(5450-METRIC)    INDM5450X580         L1                                                                                                            Inductor Fixed - Generic                        Inductor                                                                                                                                                                                                                                                                                                                                                                                                         Fixed                                                                                                                                                     
8   DNP                  R_CHIP-0805(2012-METRIC) RESC2012X65          R3, R4, R5, R6, R9, R10, R11, R12                                                                             Resistor Fixed - Generic                        Resistor                                                                                                                                                                                                                                                                                                                                                                                                         Fixed                                                                                                                                                     
1   DS-06                DS06                     DS-06                S2                                                                                                            DIL/CODE SWITCH                                 SWITCH                                                                                                                                                                                                  MCNDS-06-V                                                                                                                                                                                                                                                                        SPST                                                     DS-06                   
1   EXT. CLOCK           PINHD-1X3                1X03                 X5                                                                                                            PIN HEADER                                                                                                                                                                                                                                                                                                                                                                         92                                                                                                                                                                                                                                      
1   EXT_I                PINHD-1X2                1X02                 JP10                                                                                                          PIN HEADER                                      Headers                                                                                              Header-Straight-2 Position                                                                                                                                                           THT                      0.100" (2.54mm)                                                                                                 Headers-Male Pins                                      Board to Board or Cable-Unshrouded-Through Hole-Straight                         
1   EXT_U                PINHD-1X2                1X02                 JP12                                                                                                          PIN HEADER                                      Headers                                                                                              Header-Straight-2 Position                                                                                                                                                           THT                      0.100" (2.54mm)                                                                                                 Headers-Male Pins                                      Board to Board or Cable-Unshrouded-Through Hole-Straight                         
1   FT232RL              FT232RL_SSOP             SSOP28               U8                                                                                                            USB Bridge, USB to UART USB 2.0 UART Interface  IC_Interface                                                                                                                      FTDI Chip                                                             FT232RL                         -40 to 85°C                                                    Active                                                        Compliant                                   Controller                          0.5W                                 USB to UART                                              FT232RL                 
1   GREEN                CHIP-FLAT-G_0805         LEDC2012X110N_FLAT-G D6                                                                                                                                                            LED          GREEN                                                                                   CHIP LED FLAT                                                                                                                                                                                                                                                                                               CHIP                                                                     FLAT_TOP                                                 LED_GREEN               
1   IO_I                 PINHD-1X2                1X02                 JP9                                                                                                           PIN HEADER                                      Headers                                                                                              Header-Straight-2 Position                                                                                                                                                           THT                      0.100" (2.54mm)                                                                                                 Headers-Male Pins                                      Board to Board or Cable-Unshrouded-Through Hole-Straight                         
1   IO_U                 PINHD-1X2                1X02                 JP11                                                                                                          PIN HEADER                                      Headers                                                                                              Header-Straight-2 Position                                                                                                                                                           THT                      0.100" (2.54mm)                                                                                                 Headers-Male Pins                                      Board to Board or Cable-Unshrouded-Through Hole-Straight                         
4   ISL21080             ISL21080                 SOT-23               U1, U2, U3, U4
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

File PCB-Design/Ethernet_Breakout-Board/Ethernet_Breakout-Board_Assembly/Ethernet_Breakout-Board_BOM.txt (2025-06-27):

Partlist exported from Team Hub: Simon Dorrer   Project: JKU  Board: PCB v56 at 14.06.2024 14:19

Qty Value         Device                                   Package                        Parts                                                          Description                                                   CATEGORY         COLOR COPYRIGHT                                                CURRENT_RATING DATA-RATE    DATASHEET-URL                                           DESCRIPTION                                                                          FREQUENCY LED MANUFACTURER       MANUFACTURER_PART_NUMBER MFR_NAME          MOUNT MPN        OPERATING_TEMP OPERATING_TEMPERATURE       PART-NUMBER   PART_STATUS POE     POPULARITY PORTS RATING ROHS_COMPLIANCE ROHS_COMPLIANT SERIES SPICEPREFIX SUB-CATEGORY      SUBCATEGORY    THERMALLOSS THERMAL_LOSS TOLERANCE TP_SIGNAL_NAME TYPE             USB VALUE          VOLTAGE_RATING
1    74980100001  WE-RJ45_74980100001                      74980100001                    X7                                                             WE-RJ45 LAN Through Hole Reflow                                                                                                                              10/100BASE-T https://www.we-online.com/redexpert/spec/74980100001?ae                                                                                                -                                                                 THT                                                          74980100001              non-PoE             1                                                                                                                                                                 No   74980100001                 
10  0805_GREEN    CHIP-FLAT-G_0805                         LEDC2012X110N_FLAT-G           D1, D2, D3, D4, D5, D6, D7, D8, D9, D10                                                                                      LED              GREEN                                                                                                                                              CHIP LED FLAT                                                                                                                                                                                                                                                                                                                            CHIP                                                                               FLAT_TOP             LED_GREEN                    
6   0R            R_CHIP-0805(2012-METRIC)                 RESC2012X65                    R31, R32, R41, R42, R47, R48                                   Resistor Fixed - Generic                                      Resistor                                                                                                                                                                                                                                                                                                                                                                                                                                                                                                     Fixed                                                                                                                                
1   1.5k          R_CHIP-0603(1608-METRIC)                 RESC1608X60                    R5                                                             Resistor Fixed - Generic                                      Resistor                                                                                                                                                                                                                                                                                                                                                                                                                                                                                                     Fixed                                                                                                                                
2   100R@100MHz   L_CHIP-0603(1608-METRIC)                 INDC1608X95N                   L1, L2                                                         Inductor Fixed - Generic                                      Inductor                                                                                                                                                                                                                                                                                                                                                                                                                                                                                                     Fixed                                                                                                                                
5   100nF         C_CHIP-0603(1608-METRIC)                 CAPC1608X85                    C9, C10, C11, C12, C13                                         Capacitor - Generic                                           Capacitor                                                                                                                                                                                                                                                                                                                                                                                                                                                                                                                                                                                                                                         
10  100nF         C_CHIP-0805(2012-METRIC)                 CAPC2012X110                   C3, C4, C5, C8, C16, C17, C18, C19, C20, C21                   Capacitor - Generic                                           Capacitor                                                                                                                                                                                                                                                                                                                                                                                                                                                                                                                                                                                                                                         
1   10k           R_CHIP-0805(2012-METRIC)                 RESC2012X65                    R30                                                            Resistor Fixed - Generic                                      Resistor                                                                                                                                                                                                                                                                                                                                                                                                                                                                                                     Fixed                                                                                                                                
1   10nF/3kV      C-EU050-025X075                          C050-025X075                   C22                                                            CAPACITOR, European symbol                                                                                                                                                                                                                                                                                                                                                                                                                                                                       29                                                            C                                                                                                                                                
10  150R          R_CHIP-0805(2012-METRIC)                 RESC2012X65                    R2, R4, R15, R17, R19, R21, R23, R25, R27, R29                 Resistor Fixed - Generic                                      Resistor                                                                                                                                                                                                                                                                                                                                                                                                                                                                                                     Fixed                                                                                                                                
2   22pF          C_CHIP-0603(1608-METRIC)                 CAPC1608X85                    C1, C2                                                         Capacitor - Generic                                           Capacitor                                                                                                                                                                                                                                                                                                                                                                                                                                                                                                                                                                                                                                         
3   22uF          C-POL_TANTALUM-1411(3528-METRIC)         CAPMP3528X210N                 C6, C7, C14                                                    Capacitor Polarised - Generic                                 Capacitor                                                                                                                                                                                                                                                                                                                                                                                                                                                                                                                                                                                                                                         
1   25MHz         CRYSTAL_HC49-11.5L-3.6H                  XTALRR488W43L1150T500H368B     XT1                                                            Crystal 2Pin - Generic                                        Frequency-Source                                                                                                                                                                                                                                                                                                                                                                                                                                                                                             Crystal-2Pin                                                                                            HC49                         
1   2k            R_CHIP-0603(1608-METRIC)                 RESC1608X60                    R6                                                             Resistor Fixed - Generic                                      Resistor                                                                                                                                                                                                                                                                                                                                                                                                                                                                                                     Fixed                                                                                                                                
1   3.3V_IN       2828XX-2282837-2                         TERMBLK_508-2N                 X3                                                             2 Position Wire to Board Terminal Block Horizontal with Board Connector                                                                                                                                                             2 Position Wire to Board Terminal Block Horizontal with Board 5.08 mm Through Hole               TE Connectivity                                                     282837-2                  -40°C to +105°C                           ACTIVE                                      RoHS Compliant                 282837                               Terminal Block                                                    Side Wire Entry                                  
1   3.3V_IN       PINHD-1X3                                1X03                           X4                                                             PIN HEADER                                                    CONNECTOR                                                                                                                                                                                                                                                                                                                                                                                                                                                                                                    PIN-HEADER                                                                                                                           
1   470nF         C_CHIP-0805(2012-METRIC)                 CAPC2012X110                   C15                                                            Capacitor - Generic                                           Capacitor                                                                                                                                                                                                                                                                                                                                                                                                                                                                                                                                                                                                                                         
10  5.1k          R_CHIP-0603(1608-METRIC)                 RESC1608X60                    R7, R8, R9, R10, R11, R12, R13, R33, R34, R35                  Resistor Fixed - Generic                                      Resistor                                                                                                                                                                                                                                                                                                                                                                                                                                                                                                     Fixed                                                                                                                                
10  5.1k          R_CHIP-0805(2012-METRIC)                 RESC2012X65                    R1, R3, R14, R16, R18, R20, R22, R24, R26, R28                 Resistor Fixed - Generic                                      Resistor                                                                                                                                                                                                                                                                                                                                                                                                                                                                                                     Fixed                                                                                                                                
4   50R           R_CHIP-0805(2012-METRIC)                 RESC2012X65                    R37, R38, R39, R40                                             Resistor Fixed - Generic                                      Resistor                                                                                                                                                                                                                                                                                                                                                                                                                                                                                                     Fixed                                                                                                                                
1   749013011A    749013011ALAN-TRANSFORMER_WE-LAN_POE_W00 LAN-TRANSFORMER_WE-LAN_POE_W00 U3                                                                                                                                                  Copyright (C) 2023 Ultra Librarian. All rights reserved.                                                                                                                                                                                                           749013011A               Wurth Electronics
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

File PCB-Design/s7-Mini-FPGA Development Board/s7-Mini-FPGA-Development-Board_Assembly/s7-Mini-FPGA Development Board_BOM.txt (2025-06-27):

Partlist exported from Team Hub: EuroSkills & WorldSkills - Training AT   Project: WorldSkills 2024 - Training AT  Board: s7-Mini-FPGA Development Board v5 at 14.08.2024 23:11

Qty Value            Device                   Package              Parts                                                        Description
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

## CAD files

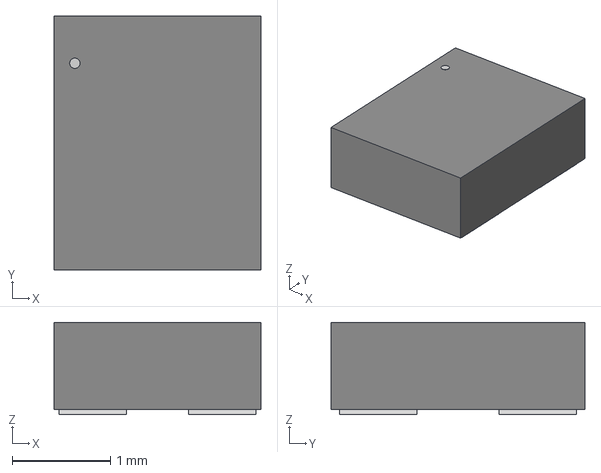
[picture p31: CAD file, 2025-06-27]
PCB-Design/ATBS_Evaluation-Board/ATBS_Evaluation-Board_Libraries/CFPS-73/CFPS-73.step
2.11 x 2.59 x 0.942 mm

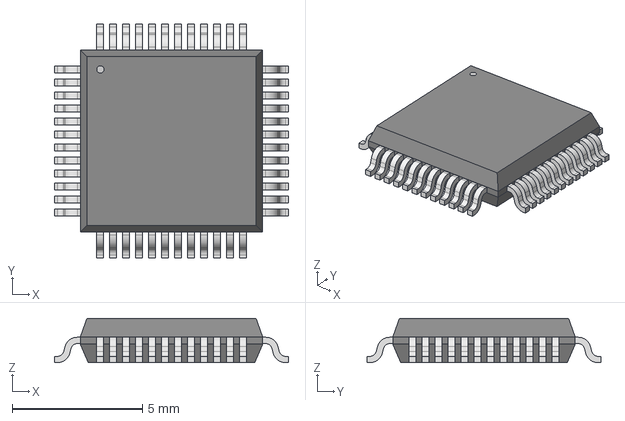
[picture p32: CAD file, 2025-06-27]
PCB-Design/Ethernet_Breakout-Board/Ethernet_Breakout-Board_Libraries/RTL8201_Lib/RTL8201L_LQFP48.step
8.99 x 8.99 x 1.70 mm

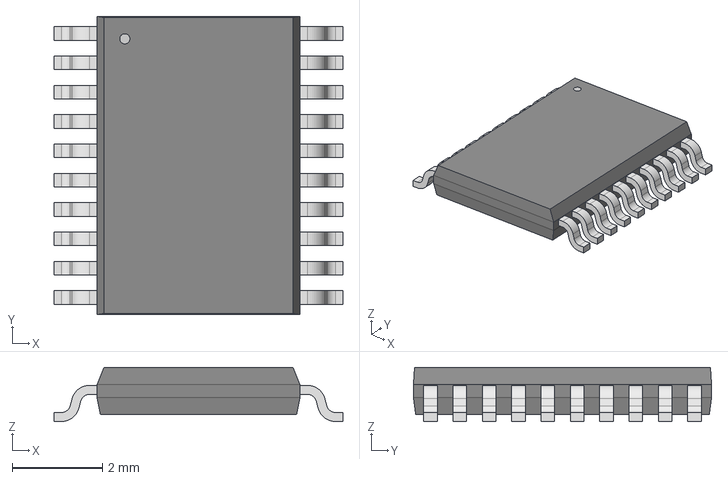
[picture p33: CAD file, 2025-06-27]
PCB-Design/TBS_Analog_Front-End/TBS_Analog_Front-End_Libraries/AD5331BRUZ/AD5331BRUZ.step
6.40 x 6.60 x 1.20 mm

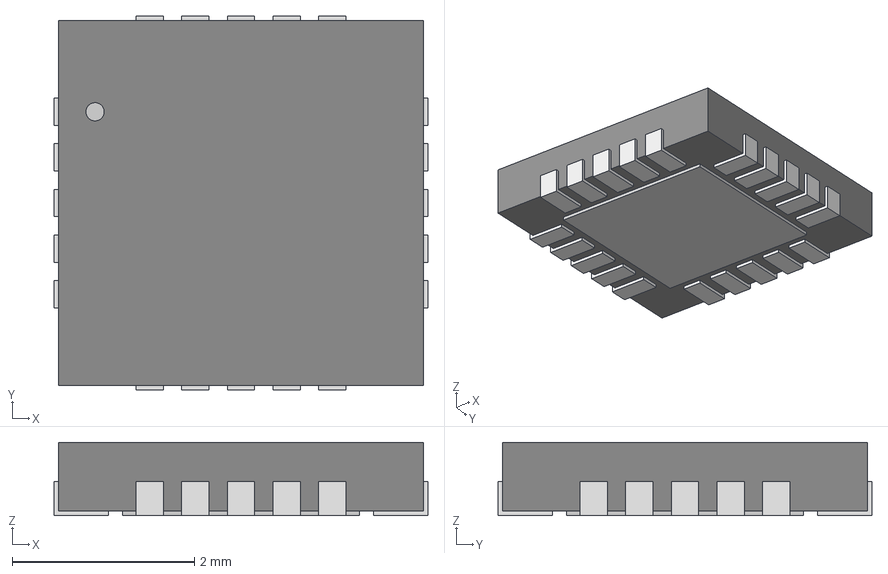
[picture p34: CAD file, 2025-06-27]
PCB-Design/TBS_Analog_Front-End/TBS_Analog_Front-End_Libraries/AD8232ACPZ-RL/AD8232ACPZ-RL.step
4.10 x 4.10 x 0.803 mm

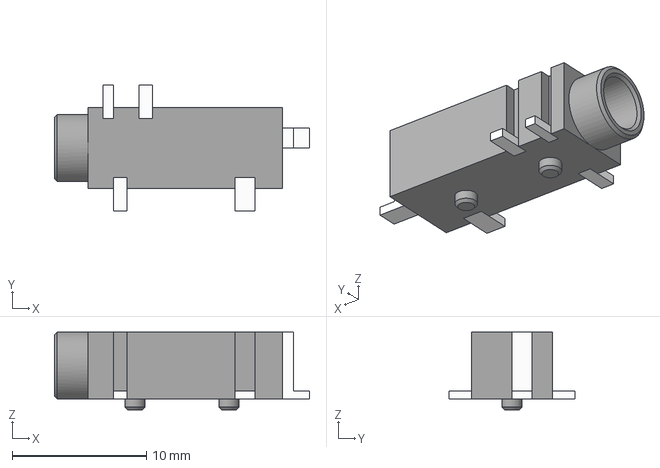
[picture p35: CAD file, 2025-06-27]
PCB-Design/TBS_Analog_Front-End/TBS_Analog_Front-End_Libraries/audio_jack.step
19.0 x 9.40 x 5.80 mm

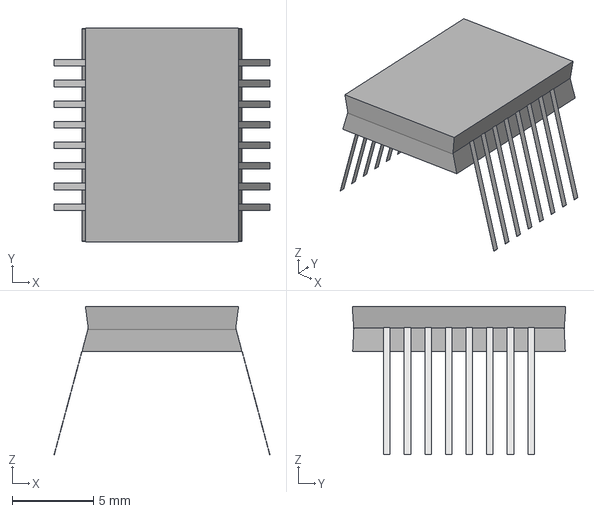
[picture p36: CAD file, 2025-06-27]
PCB-Design/Ethernet_Breakout-Board/Ethernet_Breakout-Board_Libraries/Ethernet_Trafo/749013011A.step
13.3 x 13.2 x 9.14 mm

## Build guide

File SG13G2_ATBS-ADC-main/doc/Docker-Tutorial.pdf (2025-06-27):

## Quick-Guide to first Verilog simulation

(for Windows users)

© Jakob Ratschenberger
Institute for Integrated Circuits, Johannes Kepler University

v0.1 WS2022/23

## 1 Installations

The following programs have to be downloaded and installed:

- Docker (https://docs.docker.com/desktop/install/windows-install)
- Xming X-server (https://sourceforge.net/projects/xming)

## 2 Download IIC-OSIC-TOOLS

Download the IIC-OSIC-TOOLS from GitHub (https://github.com/iic-jku/iic-osic-tools) (https://github.com/iic-jku/iic-osic-tools) as an archive and extract the files.

## 3 Setting up the environment

### 3.1 Start the X-server

Start the X-server by launching the XLaunch application. A new window opens, and the configurations should be set as in figure 1.

### 3.2 Start Docker

Start Docker and leave it as is (it takes a while to start up).

### 3.3 Start a terminal

- Start a terminal and navigate to the folder of the extracted IIC-OSIC-TOOLS archive.
- Type in

> .\ start_x.bat

and press enter.

If everything works out correctly, a new terminal window should pop up as in figure 3.

1

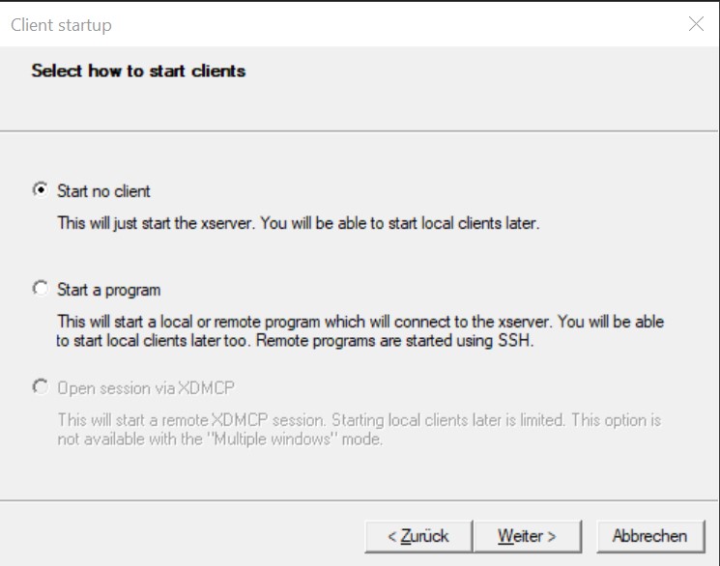
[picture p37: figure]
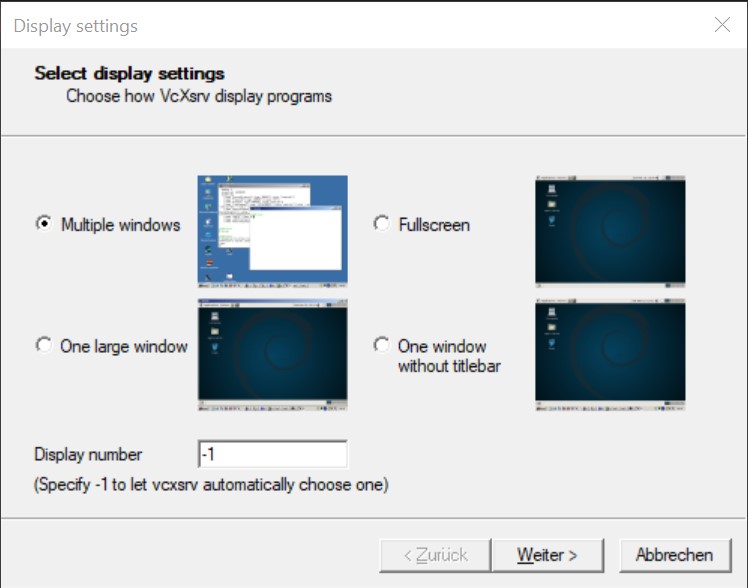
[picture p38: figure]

(a) (b)

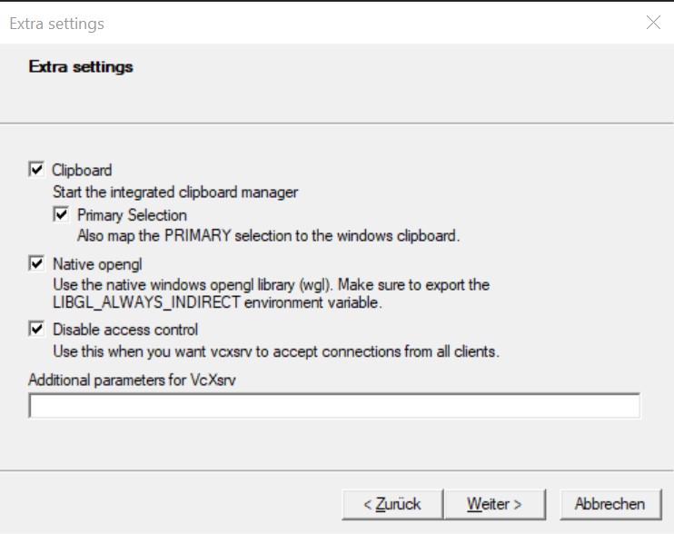
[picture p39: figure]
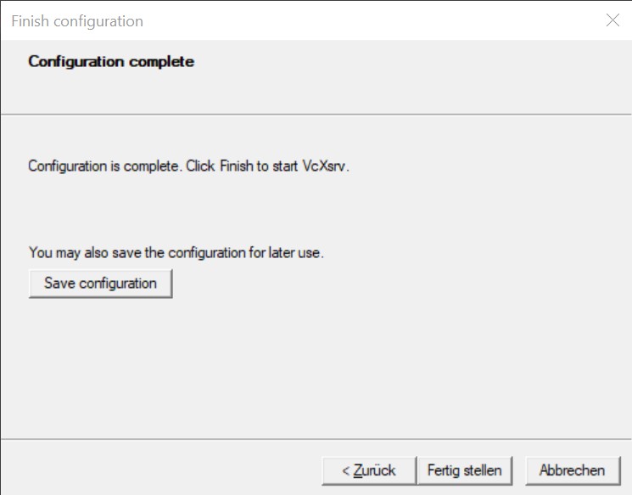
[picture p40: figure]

(c) (d)

Figure 1: XLaunch configurations.

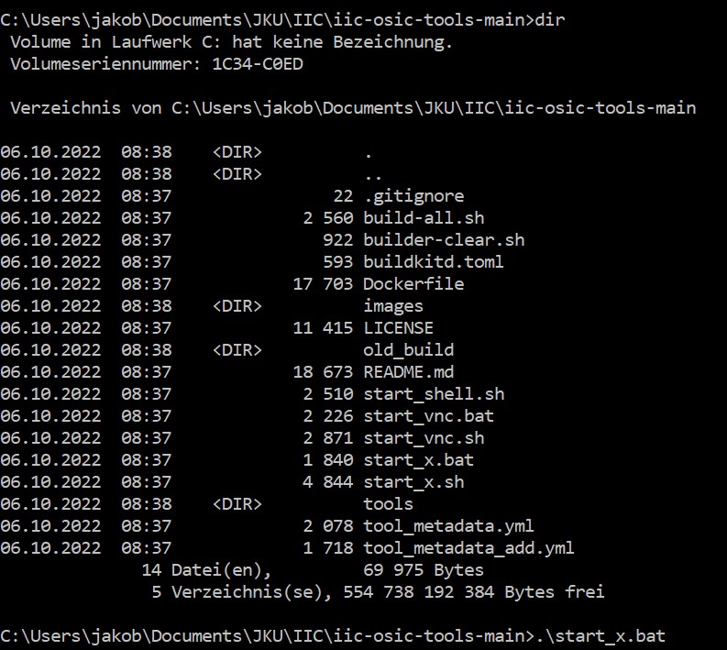
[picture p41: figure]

Figure 2: Setting up the IIC-OSIC-TOOLS in the terminal.

2

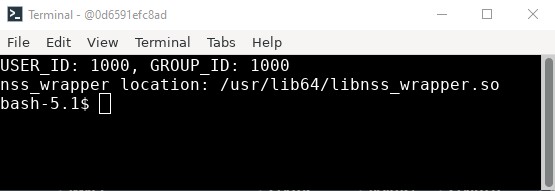
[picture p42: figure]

Figure 3: Final result.

3

## 4 First simulation

### 4.1 Create a simple binary counter

and name the file counter.v:

1 | /*
2 | Simple counter with generic bitwidth .
3 | */
4
5 | ‘default_nettype none
6 | ‘ifndef __COUNTER__
7 | ‘define __COUNTER__
8
9 | module counter
10 | #(
11 | parameter BW = 8 // optional parameter
12 | ) (
13 | // define I/O’s of the module
14 | input | clk_i , | // clock
15 | input | rst_i , | // reset
16 | output wire [ BW -1:0] | counter_val_o | // counter value
17 | );
18
19 | // start the module implementation
20
21 | // register to store the counter value
22 | reg [BW -1:0] counter_val ;
23
24 | // assign the counter value to the output
25 | assign counter_val_o = counter_val ;
26
27 | always @( posedge clk_i ) begin
28 | // gets active always when a positive edge of the clock signal occours
29
30 | if ( rst_i == 1’ b1 ) begin
31 | // if reset is enabled
32 | counter_val <= { BW {1 ’ b0 }}; // reset the counter value
33 | end else begin
34 | // increment the counter value by 1
35 | counter_val <= counter_val + {{( BW -1) {1 ’ b0 }} , 1’ b1 };
36 | end
37 | end
38
39 endmodule // counter
40
41 | ‘endif
42 | ‘default_nettype wire

### 4.2 Create a test bench for the counter

and name the file counter_tb.v:

1 | /*
2 | Simple testbench for the counter .
3 | */
4
5 ‘timescale 1 ns / 1 ns
6
7 ‘include " counter .v"
8
9 module counter_tb ;
10
11 | parameter BW = 3;
12
13 | // inputs
14 | reg | rst_i = 1’ b1 ;
15 | reg | clk_i = 1’ b0 ;
16 | wire [ BW -1:0] | cnt_val ;
17
18 | // DUT
19 | counter
20 | #( BW )
21 | counter_dut (
22 | . clk_i ( clk_i ) ,
23 | . rst_i ( rst_i ) ,
24 | . counter_val_o ( cnt_val )
25 | );
26
27 | // Generate clock
28 | /* verilator lint_off STMTDLY */
29 | always #5 clk_i = ~ clk_i ;
30 | /* verilator lint_on STMTDLY */
31
32 | initial begin
33 | $dumpfile (" counter_tb . vcd ");
34 | $dumpvars ;
35
36 | /* verilator lint_off STMTDLY */
37 | #50 rst_i = 1’ b0 ; // deassert reset
38 | #200 $finish ; // finish

4

39 | /* verilator lint_on STMTDLY */
40 | end
41
42 endmodule // counter_tb

### 4.3 Save the files in the working directory

Go to the directory C:\Users\USERNAME\eda\designs\ and make a new subdirectory named \FirstSimulation. Now save counter.v and counter_tb.v in this directory.

If your terminal window isn’t open, you could easily start a new one, by restarting the container in the Docker application.

Now check if the files are in the \FirstSimulation directory. If all worked out well, the result should look similar as in figure 4.

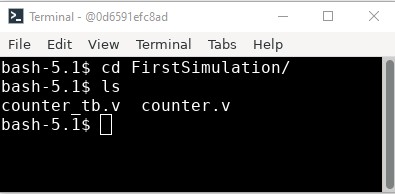
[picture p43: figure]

Figure 4: File navigation.

### 4.4 Check the code

To check the code for possible syntax errors (or typical coding mistakes), the tool iic-vlint.sh can be used. The syntax is as follows:

> iic-vlint.sh <file.v>

### 4.5 Compile the program

To compile the program, Icarus Verilog will be used. For compiling the Verilog code, the syntax is as follows:

> iverilog -g2005 -o <OUTPUTFILE_NAME> <file.v>

Now compile the program by

> iverilog -g2005 -o COUNTER counter_tb.v

### 4.6 Execute the compiled program

The compiled program can be executed by the following command:

> vvp <OUTPUTFILE_NAME>

Therefore, to execute our counter, type in

> vvp COUNTER

5

If everything worked out correctly, the results should look like in figure 5.

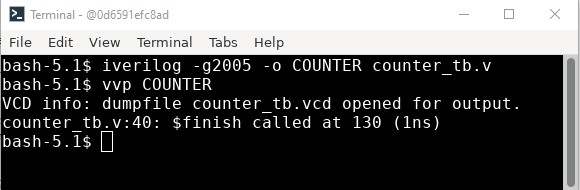
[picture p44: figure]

Figure 5: Compiled and executed counter.

### 4.7 Look at the waveform

Since we dumped all variables in the result file counter_tb.vcd we can investigate our counter design. For this, we use gtkwave, which is a waveform plotting tool for digital signals.

To view the waveforms of our counter, type in and execute:

> gtkwave counter_tb.vcd

Now a new window pops up and the waveforms can be investigated. The results should look like in figure 6.

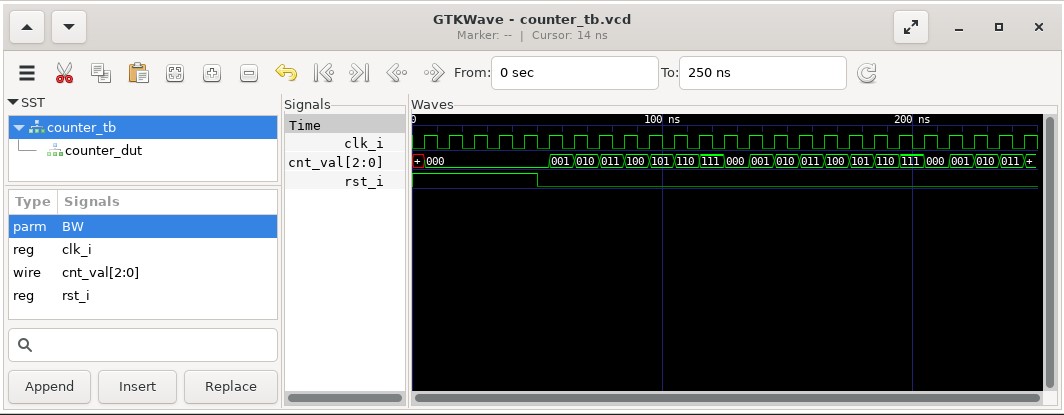
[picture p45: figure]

Figure 6: Waveforms of the counter.

6

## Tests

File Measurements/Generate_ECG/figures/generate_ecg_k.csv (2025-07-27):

k | ecg_signal | ecg_signal_scaled | ecg_data_offset
0 | -0.0101 | -0.0393506493506494 | 1.38954545454545
1 | -0.00834999999999997 | -0.0325324675324674 | 1.39636363636364
2 | -0.00854999999999995 | -0.0333116883116881 | 1.39558441558442
3 | -0.00495000000000001 | -0.0192857142857143 | 1.40961038961039
4 | -0.001 | -0.0038961038961039 | 1.425
5 | 0.00180000000000002 | 0.00701298701298709 | 1.43590909090909
6 | 0.00470000000000004 | 0.0183116883116885 | 1.44720779220779
7 | 0.00570000000000004 | 0.0222077922077924 | 1.4511038961039
8 | 0.003 | 0.0116883116883117 | 1.44058441558442
9 | 0.000250000000000083 | 0.000974025974026297 | 1.42987012987013
10 | -0.000599999999999934 | -0.00233766233766208 | 1.42655844155844
11 | 0.000500000000000056 | 0.00194805194805217 | 1.43084415584416
12 | 0.00535000000000008 | 0.0208441558441562 | 1.44974025974026
13 | 0.00970000000000004 | 0.0377922077922079 | 1.46668831168831
14 | 0.0118 | 0.045974025974026 | 1.47487012987013
15 | 0.00875000000000004 | 0.0340909090909092 | 1.46298701298701
16 | 0.00445000000000007 | 0.0173376623376626 | 1.44623376623377
17 | 0.000800000000000023 | 0.00311688311688321 | 1.43201298701299
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

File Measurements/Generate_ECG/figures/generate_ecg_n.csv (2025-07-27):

n | ecg_data_interp | ecg_signal_quant
0 | 1.38954545454356 | 7227
1 | 1.39182199680411 | 7239
2 | 1.39387055773371 | 7249
3 | 1.3954436843081 | 7258
4 | 1.39636363636173 | 7262
5 | 1.39572387854739 | 7259
6 | 1.39498724393125 | 7255
7 | 1.39477851637532 | 7254
8 | 1.39558441558248 | 7258
9 | 1.39739119826286 | 7268
10 | 1.4005256572265 | 7284
11 | 1.40475752629335 | 7306
12 | 1.40961038960845 | 7331
13 | 1.41367983276659 | 7352
14 | 1.417661477878 | 7373
15 | 1.42146205022021 | 7393
16 | 1.42499999999807 | 7411
17 | 1.42764957853686 | 7425
18 | 1.43023468314311 | 7439
19 | 1.43296140091641 | 7453
20 | 1.43590909090715 | 7468
21 | 1.43844184343604 | 7481
22 | 1.44124279491938 | 7496
23 | 1.44424805059713 | 7511
24 | 1.44720779220586 | 7527
25 | 1.44915756945506 | 7537
26 | 1.45056542023086 | 7544
27 | 1.45127372918009 | 7548
28 | 1.45110389610196 | 7547
29 | 1.44920732757152 | 7537
30 | 1.44660929953384 | 7524
31 | 1.44364421792096 | 7508
32 | 1.44058441558246 | 7492
33 | 1.4370588955315 | 7474
34 | 1.43398972642928 | 7458
35 | 1.43158747011258 | 7446
36 | 1.42987012986815 | 7437
37 | 1.42814072153354 | 7428
38 | 1.4270333617088 | 7422
39 | 1.42653406923593 | 7419
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

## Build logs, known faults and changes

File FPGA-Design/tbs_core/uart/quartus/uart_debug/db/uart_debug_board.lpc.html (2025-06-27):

Hierarchy | Input | Constant Input | Unused Input | Floating Input | Output | Constant Output | Unused Output | Floating Output | Bidir | Constant Bidir | Unused Bidir | Input only Bidir | Output only Bidir
uart_0|uart_rx_0 | 12 | 0 | 0 | 0 | 9 | 0 | 0 | 0 | 0 | 0 | 0 | 0 | 0
uart_0|uart_tx_0 | 20 | 0 | 0 | 0 | 2 | 0 | 0 | 0 | 0 | 0 | 0 | 0 | 0
uart_0 | 21 | 1 | 0 | 1 | 11 | 1 | 1 | 1 | 0 | 0 | 0 | 0 | 0
PLL50to8|pll_8mhz_inst | 2 | 0 | 0 | 0 | 2 | 0 | 0 | 0 | 0 | 0 | 0 | 0 | 0
PLL50to8 | 2 | 1 | 0 | 1 | 2 | 1 | 1 | 1 | 0 | 0 | 0 | 0 | 0

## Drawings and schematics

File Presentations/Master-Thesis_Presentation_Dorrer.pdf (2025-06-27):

# An Open-Source Adaptive Event-Based ADC for

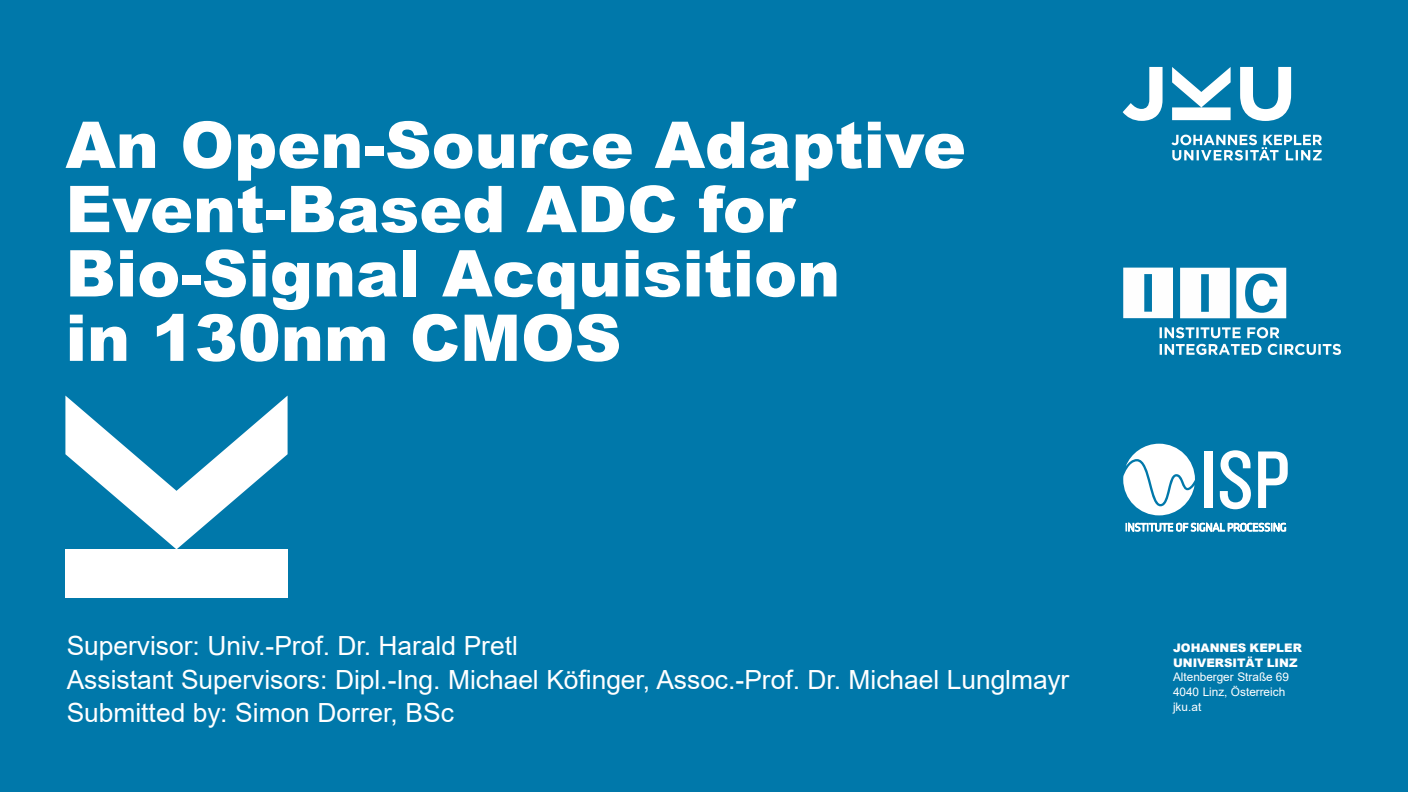
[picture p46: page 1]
JOHANNES KEPLER UNIVERSITÄT LINZ Altenberger Straße 69 4040 Linz, Österreich jku.at

Bio-Signal Acquisition
in 130nm CMOS

Supervisor: Univ.-Prof. Dr. Harald Pretl
Assistant Supervisors: Dipl.-Ing. Michael Köfinger, Assoc.-Prof. Dr. Michael Lunglmayr
Submitted by: Simon Dorrer, BSc

## Thesis Organization

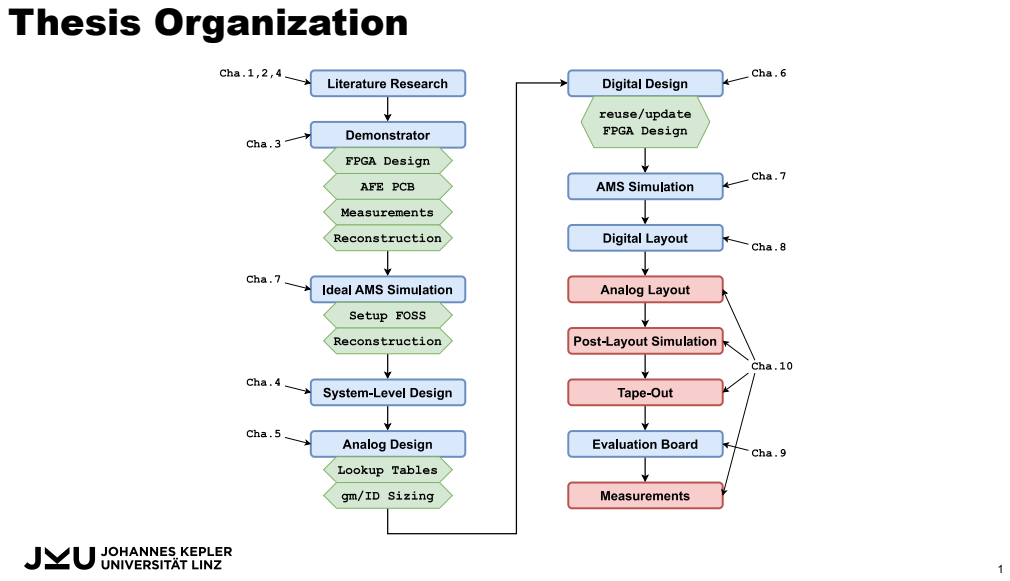
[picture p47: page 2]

# Theoretical Background

## Nyquist vs. Event-Based ADC

- Nyquist ADCs sample input at a fixed sample rate → uniform samples
- Voltage values are quantized and encoded → amplitude quantization
- Event-based ADCs only produce samples when input exceeds a predefined threshold → non-uniform event pulses (spikes)
- Time between spikes is measured and encoded → time quantization
- For sparse signals, event-based ADCs significantly decrease:

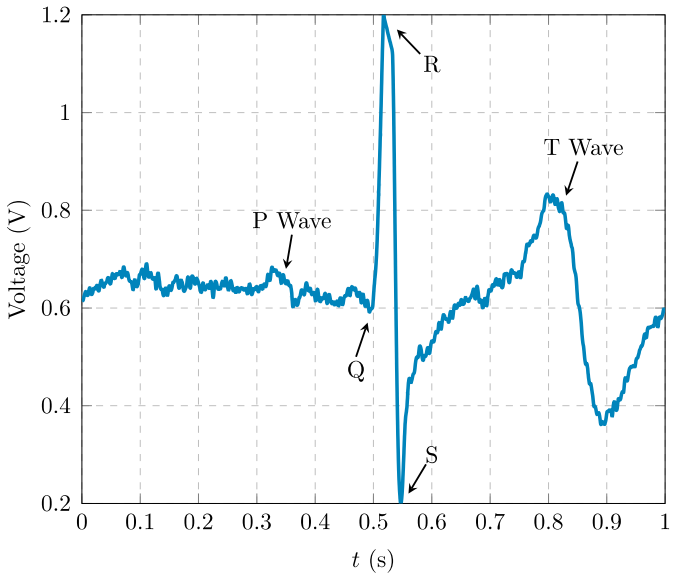
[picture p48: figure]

- number of samples
- storage resources
- computational effort
- power consumption

## Nyquist vs. Event-Based ADC – Time Domain

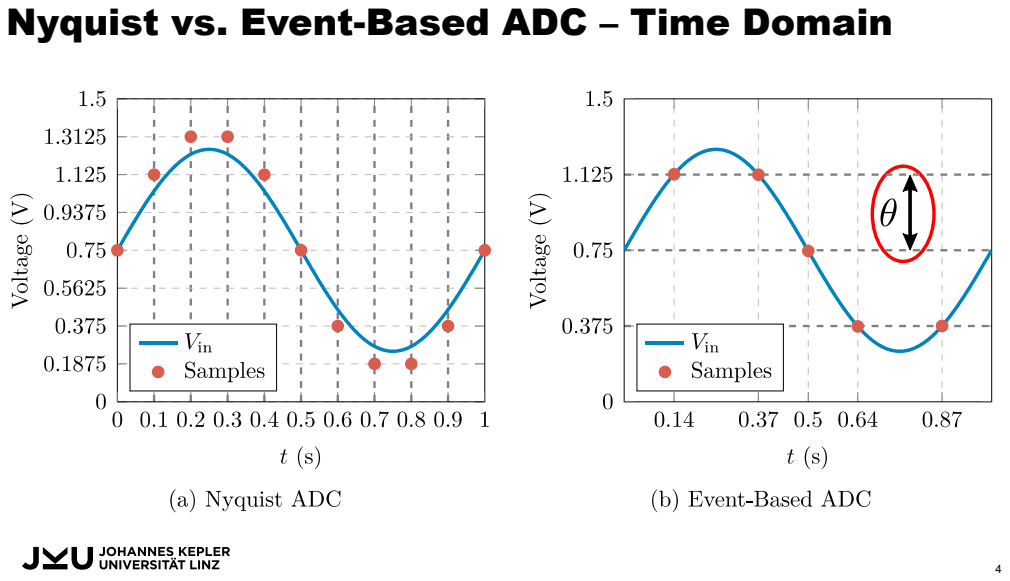
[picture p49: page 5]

## Floating-Window Architecture

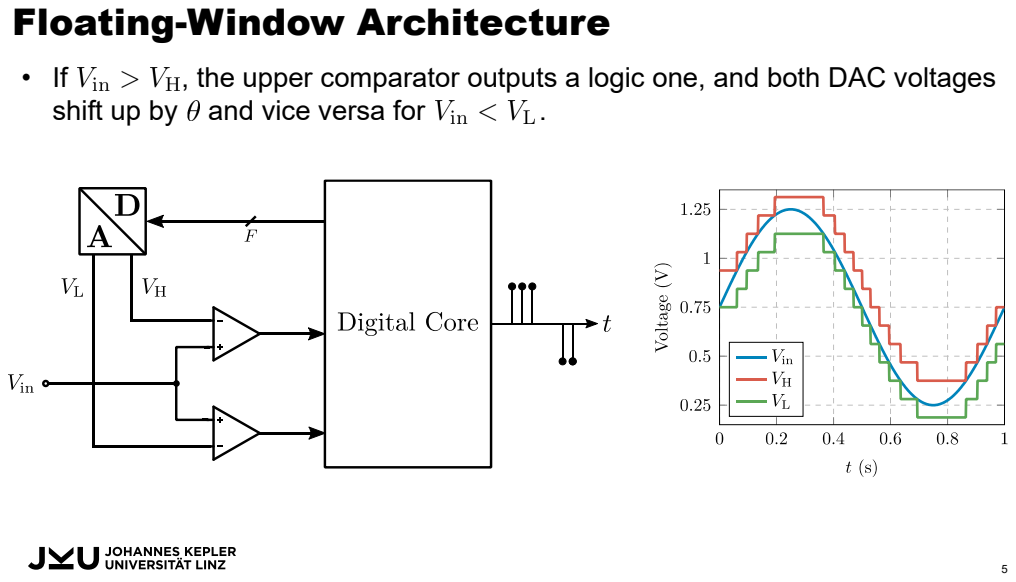
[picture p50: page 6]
, the upper comparator outputs a logic one, and both DAC voltages; shift up by and vice versa for

## Fixed-Window Architecture

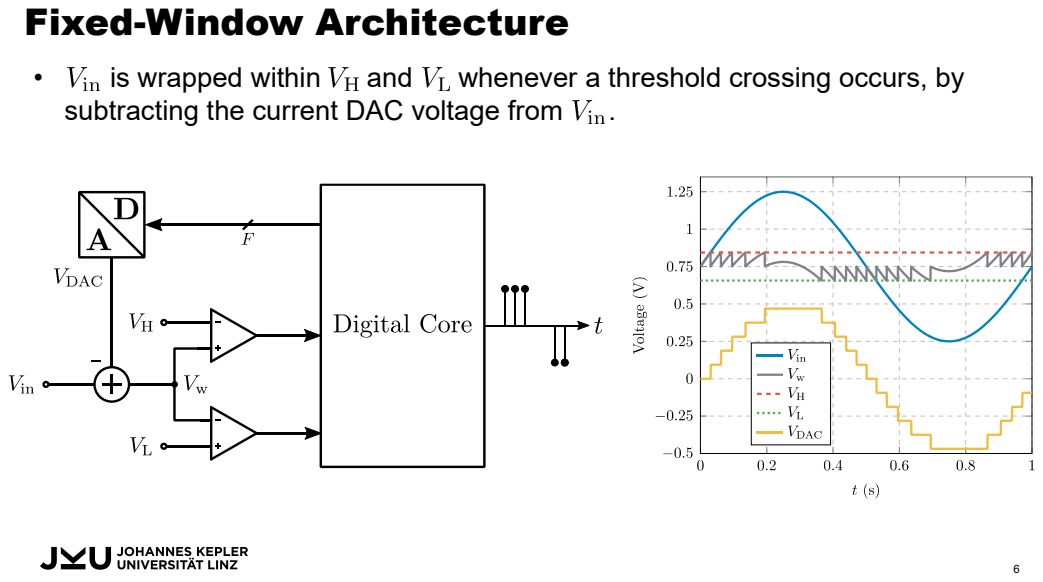
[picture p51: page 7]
is wrapped within; and; whenever a threshold crossing occurs, by; subtracting the current DAC voltage from

## Nyquist vs. Event-Based ADC – Aliasing

- Nyquist ADC: The sampling limit induced by aliasing is defined by the Shannon-Nyquist theorem:
- Event-based ADC: The aliasing effect is caused by their slew rate:
- The maximum frequency for sine waves ( | ) for event-based
ADCs with fixed thresholds can be expressed as:

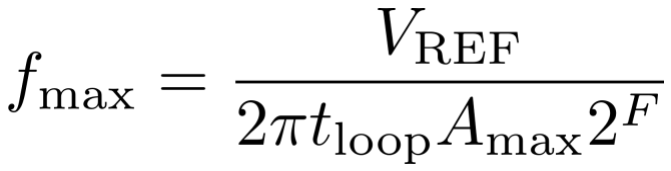
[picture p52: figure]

## Nyquist vs. Event-Based ADC – SQNR

- Nyquist ADC: The time- and frequency-domain SQNR for a full-scale amplitude sine wave, resulting from uniformly distributed amplitude quantization, depends on the ADC resolution ( ):
- Event-based ADCs: The SQNR, resulting from time quantization, depends
on the clock resolution ( | ) and the input signal’s frequency ( | ):
- Event-based ADCs can achieve an SQNR equivalent to that of an -bit
Nyquist ADC while requiring only a DAC with fewer than | bits ( | ).
where | is the resolution or oversampling ratio:

## Continuous-Time vs. Discrete-Time

- Continuous-time (CT) system:
- CT comparator, CT DAC, and asynchronous or clockless digital core
- Minimize clock uncertainty and loop delay
- Ideally, no amplitude and no time quantization and no aliasing!
- Limited by high power consumption and nonidealities of AFE
- Discrete-time (DT) system:
- Trigger AFE periodically or adaptively
- Reduction of power consumption
- Introduction of clock uncertainty and limiting the slew rate to:

## Adaptive Threshold-Based Sampling

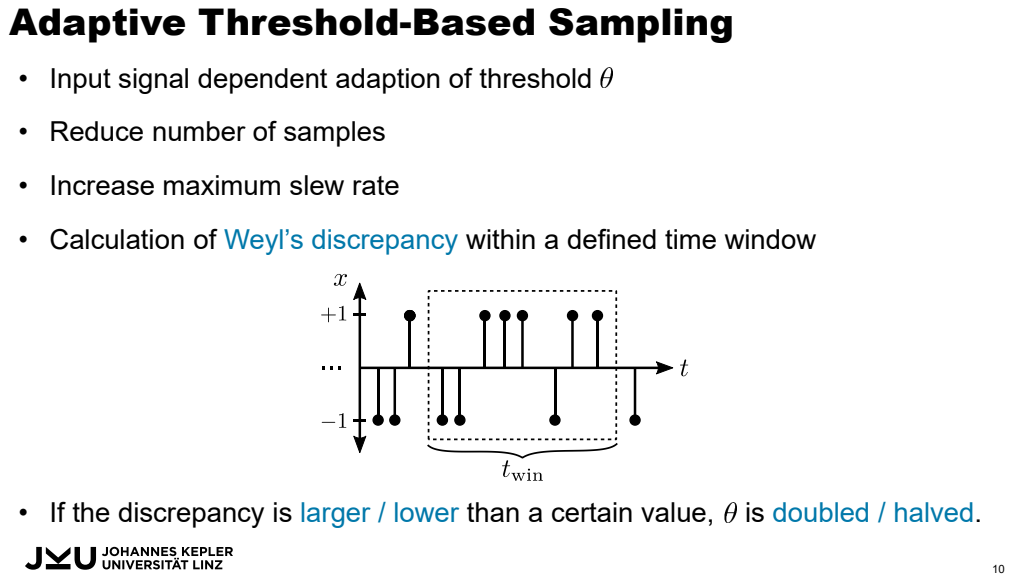
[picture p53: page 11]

• Input signal dependent adaption of threshold

• Reduce number of samples

• Increase maximum slew rate

• Calculation of Weyl’s discrepancy within a defined time window

• If the discrepancy is larger / lower than a certain value, is doubled / halved.

## State of the Art

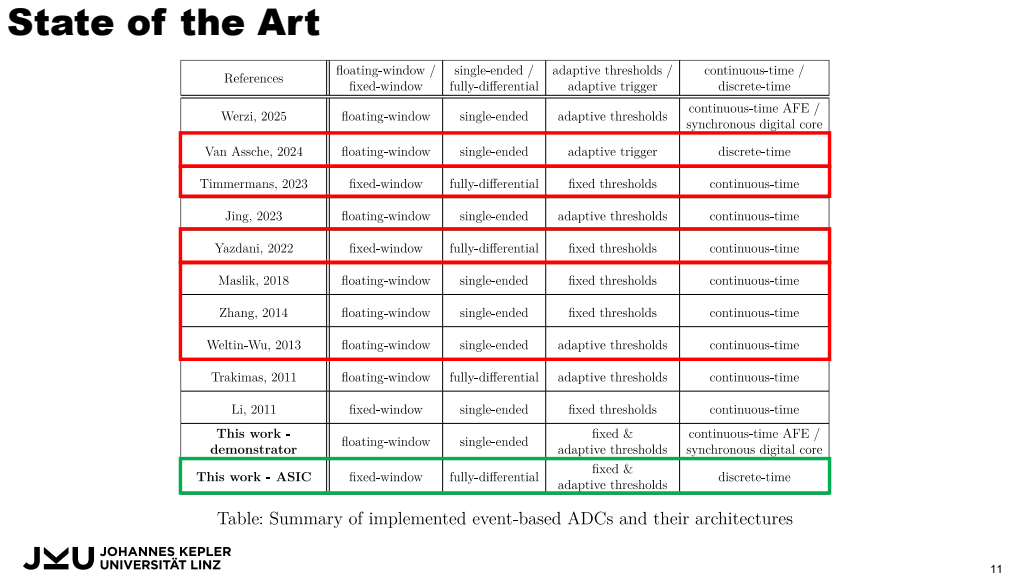
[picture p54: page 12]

# PCB-Level Demonstrator

## Block Diagram

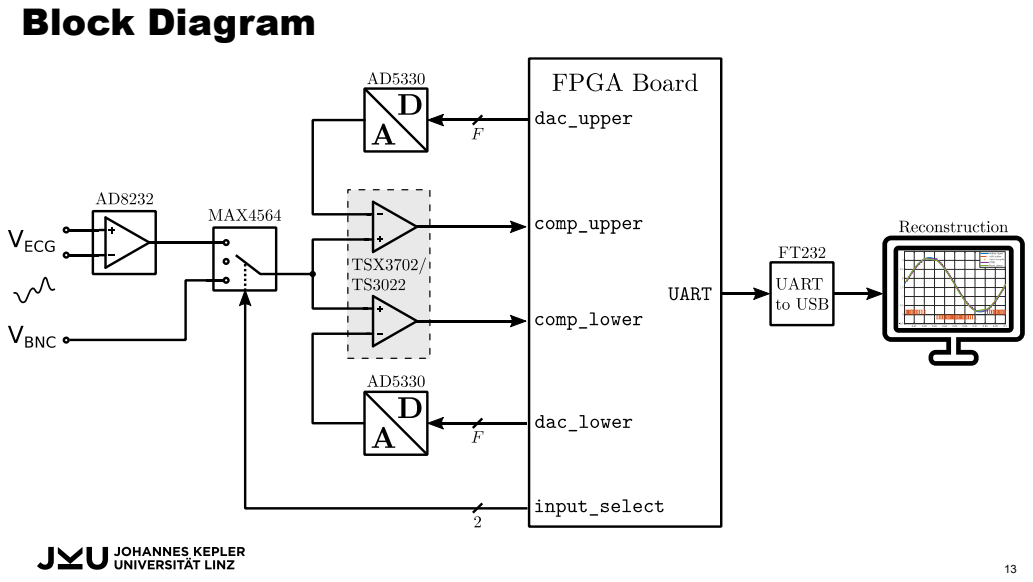
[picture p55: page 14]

## Analog Front-End PCB

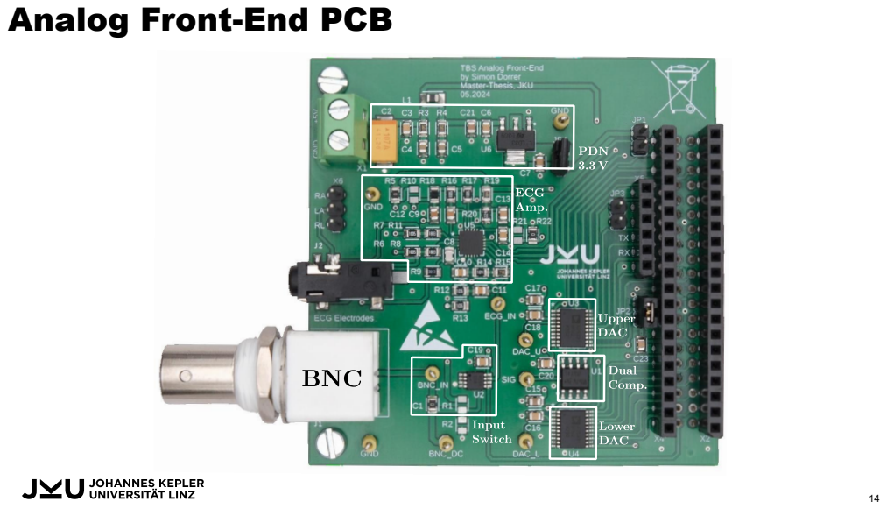
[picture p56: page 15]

## Reconstruction Results – ECG – TBS

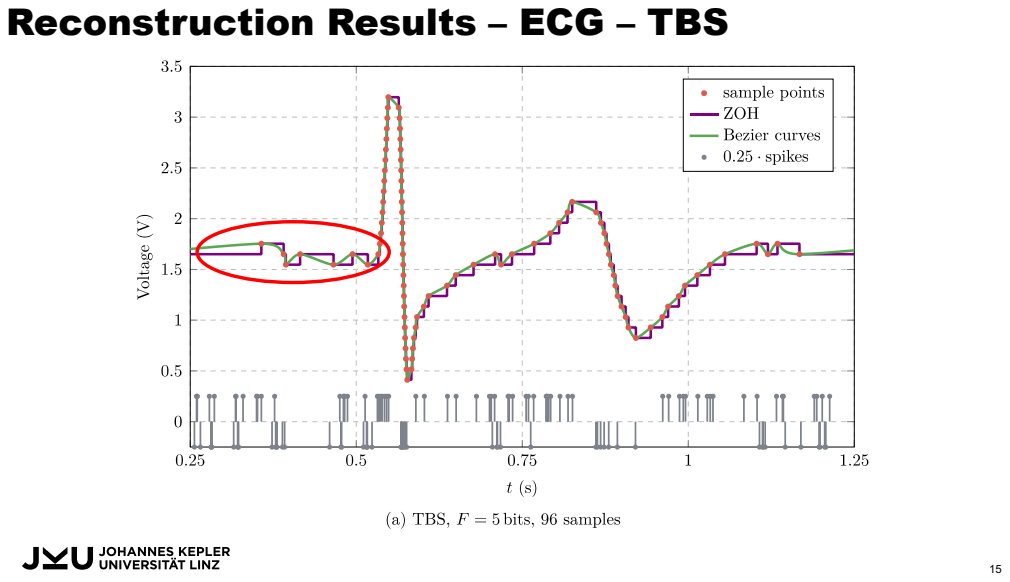
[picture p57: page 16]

## Reconstruction Results – ECG – ATBS


## Reconstruction Results – ECG – ATBS


## Reconstruction Results – ECG – ATBS


## Reconstruction Results – Sine


# ASIC Design

## Block Diagram


## Upper DAC + Comparator – Transient Simulation


## Lower DAC + Comparator – Transient Simulation


# Conclusion

## Conclusion

- Achievements:
- Important theoretical findings
- Proof of concept with PCB-level demonstrator
- Development of new architecture
- Transistor-level design
- Outlook:
- Analog Layout
- Post-layout simulation
- Tape-out
- Chip verification with measurements


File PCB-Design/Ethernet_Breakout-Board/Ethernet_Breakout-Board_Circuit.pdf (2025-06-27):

## 3 X2

3 C3 | C4 C5 C6 C7 | C8 C9 | C10 C11 L1 | C12 L2 C13 C14 R30 | C15 R31 R32 S2


+ 14.06.2024 14:16 1/1 Schematic v61 Date: Sheet: REV: TITLE: Document Number: 1. This configuration shows -) Enable: Auto negotiation, FD 100Mbps, Link Down Power Saving, MII interface -) Disable: Isolate, Repeater mode 2. These seven configuration pins could be connected to VDD or GND directly. You can set PHY address from 00001b to 11111b with the corresponding Jumpers JP1-JP5. Refer to datasheet's detailed description.

X1X1 TPTX_P TPTX_P TPTX_N TPTX_N TPRX_P TPRX_P TPRX_N TPRX_N CRS CRS CRS PWFBOUT PWFBOUT PWFBOUT PWFBOUT PWFBIN PWFBIN AVDD AVDD FPGA_+5V FPGA_+5V FPGA_+3.3V FPGA_+3.3V TDCT TDCT RDCT RDCT MDC_0R MDC_0R MDIO_0R MDIO_0R AUTHOR: Simon Dorrer, AK123109

1 VO 2*2 TXC TXC TXEN TXEN TXD3 TXD3 TXD2 TXD2 TXD1 TXD1 TXD0 TXD0 RXD3 RXD3 RXD2 RXD2 RXD1 RXD1 RXD0 RXD0 RXDV RXDV RXER

RXER RXER RXC RXC LED0 LED0 LED1 LED1 LED2 LED2 LED3 LED3 LED4 LED4 PHY_RST PHY_RST COL PHY_RST

COL COL MII/SNIB/TXD5 MII/SNIB/TXD5 ISOLATE ISOLATE LDPS LDPS RPTR/RTT2 RPTR/RTT2 SPEED SPEED DUPLEX DUPLEX ANE ANE MDIO MDIO MDIO MDIO MDC MDC MDC X2









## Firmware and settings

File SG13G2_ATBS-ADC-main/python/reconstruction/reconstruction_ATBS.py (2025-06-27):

# -*- coding: utf-8 -*-
# Master-Thesis
# @ JKU IIC / ISP
# 2024
# Author: Simon Dorrer
# Description: Converts the signed 16-Bit data with overflow zeros to the 
# corresponding spikes and ATBS reconstructed signal.
# Created: 27.12.2024
# Last Modified: 27.12.2024
# ============================================

# Imports
import numpy as np
# ============================================

# Function reconstruction_ATBS
def reconstruction_ATBS(data, thmin, thmax, dmin, dmax, abs_t, time_win, offset, 
                        buffer_size, vmax, mode):
    """
    Author: Anna Werzi
    Converted from Matlab to Python by Simon Dorrer
    Last Modified: 27.12.2024
    Description: Converts the signed 16-Bit data with overflow zeros to the corresponding spikes and ATBS reconstructed signal.

    Parameters:
    data          : numpy array of 16-bit signed data with overflow zeros
    thmin         : minimum voltage delta between subsequent spikes (threshold)
    thmax         : maximum voltage delta between subsequent spikes (threshold)
    dmin          : minimum Weyl's discrepancy for adaptation algorithm
    dmax          : maximum Weyl's discrepancy for adaptation algorithm
    abs_t         : absolute time in seconds corresponding to data samples
    time_win      : time window for evaluating local Weyl's discrepancy
    offset        : offset voltage for asymmetric supply
    buffer_size   : estimated upper boundary for spikes within the chosen time window
    vmax          : voltage limit (restricted to remain below supply range)
    mode          : '1' - adapt on overflow and spike, '0' - solely adapt on spike

    Returns:
    amp           : reconstructed signal amplitude
    valid_spikes  : spikes triggered by input signal
    t             : absolute time stamps corresponding to valid_spikes
    phantom_spikes: spikes not representing sample points (triggered after overflow adaptation)
    phantom_t     : absolute time stamps corresponding to phantom_spikes
    thlist        : list of adapted thresholds during sampling
    """

    # Initialize variables
    spikes = np.sign(data[np.nonzero(data)])  # remove overflow zeros and calculate spike signs
    v_init = offset + thmin
    amp = []
    t = []
    phantom_t = []
    valid_spikes = []
    phantom_spikes = []
    thlist = []

    spikes_valid = 1
    prev_sign = 0
    curr_amp = v_init
    th = thmin
    i = -1; # spike index
    phantomspikes = 0
    vmax = vmax + offset

    start = np.argmax(data != 0)  # Find the first non-zero data index

    for j in range(start, len(data)):
        adapt_on_spike = data[j] != 0
        adapt_on_overflow = (mode == 1) and (th != thmin and data[j] == 0 and data[j-1] == 0)

        if adapt_on_overflow:
            phantomspikes = np.log2(th / thmin)  # maximal phantom spikes (if th is reduced (>>2) until thmin)
            th = th / 2
            # signal level (midpoint between DAC levels; curr_amp) does not change at overflow adaption

        if adapt_on_spike: # real or phantomspike
        
            i = i + 1
            
            if prev_sign != spikes[i]:  # check for a sign change
                spikes_valid = 1  # signal is now captured
            
            # amplitude and threshold tracking
            curr_amp = curr_amp + th * spikes[i]

            # calculate weyls discrepancy over time window
            idx = i
            spikereg = []
            while idx >= 0 and (abs_t[i] - abs_t[idx] <= time_win):
                if len(spikereg) < buffer_size:
                    spikereg.append(spikes[idx])
                    idx = idx - 1
                else:
                    print(len(spikereg))
                    break
            csum = np.cumsum(spikereg)
            w = max(0, max(csum, default=0)) - min(0, min(csum, default=0))

            prevth = th

            # adapt threshold
            if w > dmax and th < thmax:
                th = th * 2
            elif w < dmin and th > thmin:
                th = th / 2
            
            # remove phantomspikes caused by adaption at timer overflow
            if phantomspikes != 0:
                if i != len(spikes) - 1 and spikes[i] != spikes[i+1]: # direction change on next spike
                    phantomspikes = 0
                elif prevth == th: # no th reduction
                    phantomspikes = 0 # future spikes are correct
                else:
                    phantomspikes = phantomspikes - 1
                    
                # keep track of dicarded spikes
                phantom_spikes.append(spikes[i])
                phantom_t.append(abs_t[i])
            # remove phantomspikes
            elif spikes_valid == 0:
                # keep track of dicarded spikes
                phantom_spikes.append(spikes[i])
                phantom_t.append(abs_t[i])
            else:
                # valid signal sample
                amp.append(curr_amp)
                thlist.append(prevth)
                valid_spikes.append(spikes[i])
                t.append(abs_t[i])

            # Clipping
            if abs(curr_amp + spikes[i] * th) > vmax: # check in both directions
                th = prevth # shift window instead of adaption
                curr_amp = curr_amp + spikes[i] * (vmax - th - abs(curr_amp)) # adjust center of threshold window

    return amp, valid_spikes, t, phantom_spikes, phantom_t, thlist
# ============================================

if __name__ == '__main__':
    print("This code will not be executed when this file is imported.")
# ============================================

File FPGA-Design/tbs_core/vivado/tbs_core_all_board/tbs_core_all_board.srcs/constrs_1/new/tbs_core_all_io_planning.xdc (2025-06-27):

set_property CLOCK_DEDICATED_ROUTE FALSE [get_nets PLL100to50/inst/clk_in1_pll_50MHz]
set_property CFGBVS VCCO [current_design]
set_property CONFIG_VOLTAGE 3.3 [current_design]

 set_property BITSTREAM.General.UnconstrainedPins {Allow} [current_design]

set_property IOSTANDARD LVCMOS33 [get_ports {dac_lower_o[9]}]
set_property IOSTANDARD LVCMOS33 [get_ports {dac_lower_o[8]}]
set_property IOSTANDARD LVCMOS33 [get_ports {dac_lower_o[7]}]
set_property IOSTANDARD LVCMOS33 [get_ports {dac_lower_o[6]}]
set_property IOSTANDARD LVCMOS33 [get_ports {dac_lower_o[5]}]
set_property IOSTANDARD LVCMOS33 [get_ports {dac_lower_o[4]}]
set_property IOSTANDARD LVCMOS33 [get_ports {dac_lower_o[3]}]
set_property IOSTANDARD LVCMOS33 [get_ports {dac_lower_o[2]}]
set_property IOSTANDARD LVCMOS33 [get_ports {dac_lower_o[1]}]
set_property IOSTANDARD LVCMOS33 [get_ports {dac_lower_o[0]}]
set_property IOSTANDARD LVCMOS33 [get_ports {dac_upper_o[9]}]
set_property IOSTANDARD LVCMOS33 [get_ports {dac_upper_o[8]}]
set_property IOSTANDARD LVCMOS33 [get_ports {dac_upper_o[7]}]
set_property IOSTANDARD LVCMOS33 [get_ports {dac_upper_o[6]}]
set_property IOSTANDARD LVCMOS33 [get_ports {dac_upper_o[5]}]
set_property IOSTANDARD LVCMOS33 [get_ports {dac_upper_o[4]}]
set_property IOSTANDARD LVCMOS33 [get_ports {dac_upper_o[3]}]
set_property IOSTANDARD LVCMOS33 [get_ports {dac_upper_o[2]}]
set_property IOSTANDARD LVCMOS33 [get_ports {dac_upper_o[1]}]
set_property IOSTANDARD LVCMOS33 [get_ports {dac_upper_o[0]}]
set_property IOSTANDARD LVCMOS33 [get_ports adaptive_mode_i]
set_property IOSTANDARD LVCMOS33 [get_ports amp_sdn_o]
set_property IOSTANDARD LVCMOS33 [get_ports analog_trigger_o]
set_property IOSTANDARD LVCMOS33 [get_ports clock_i]
set_property IOSTANDARD LVCMOS33 [get_ports comp_lower_i]
set_property IOSTANDARD LVCMOS33 [get_ports comp_upper_i]
set_property IOSTANDARD LVCMOS33 [get_ports control_mode_i]
set_property IOSTANDARD LVCMOS33 [get_ports dac_clr_o]
set_property IOSTANDARD LVCMOS33 [get_ports dac_pd_o]
set_property IOSTANDARD LVCMOS33 [get_ports dac_wr_lower_o]
set_property IOSTANDARD LVCMOS33 [get_ports dac_wr_upper_o]
set_property IOSTANDARD LVCMOS33 [get_ports ecg_led_o]
set_property IOSTANDARD LVCMOS33 [get_ports ecg_lod_n_i]
set_property IOSTANDARD LVCMOS33 [get_ports ecg_lod_p_i]
set_property IOSTANDARD LVCMOS33 [get_ports idle_led_o]
set_property IOSTANDARD LVCMOS33 [get_ports overflow_led_o]
set_property IOSTANDARD LVCMOS33 [get_ports reset_n_i]
set_property IOSTANDARD LVCMOS33 [get_ports sc_noc_1_o]
set_property IOSTANDARD LVCMOS33 [get_ports sc_noc_2_o]
set_property IOSTANDARD LVCMOS33 [get_ports select_tbs_delta_steps_i]
set_property IOSTANDARD LVCMOS33 [get_ports signal_select_en_o]
set_property IOSTANDARD LVCMOS33 [get_ports signal_select_in_o]
set_property IOSTANDARD LVCMOS33 [get_ports trigger_start_mode_i]
set_property IOSTANDARD LVCMOS33 [get_ports trigger_start_sampling_i]
set_property IOSTANDARD LVCMOS33 [get_ports uart_rx_i]
set_property IOSTANDARD LVCMOS33 [get_ports uart_tx_o]
set_property IOSTANDARD LVCMOS33 [get_ports underflow_led_o]

set_property PACKAGE_PIN L5 [get_ports clock_i]

set_property PACKAGE_PIN F3 [get_ports idle_led_o]
set_property PACKAGE_PIN F4 [get_ports overflow_led_o]
set_property PACKAGE_PIN H3 [get_ports underflow_led_o]
set_property PACKAGE_PIN J3 [get_ports ecg_led_o]
set_property PACKAGE_PIN B2 [get_ports trigger_start_mode_i]


set_property PACKAGE_PIN C5 [get_ports {dac_lower_o[0]}]
set_property PACKAGE_PIN D10 [get_ports {dac_lower_o[1]}]
set_property PACKAGE_PIN E4 [get_ports {dac_lower_o[2]}]
set_property PACKAGE_PIN D13 [get_ports {dac_lower_o[3]}]
set_property PACKAGE_PIN C3 [get_ports {dac_lower_o[4]}]
set_property PACKAGE_PIN F13 [get_ports {dac_lower_o[5]}]
set_property PACKAGE_PIN B1 [get_ports {dac_lower_o[6]}]
set_property PACKAGE_PIN G14 [get_ports {dac_lower_o[7]}]
set_property PACKAGE_PIN F12 [get_ports {dac_lower_o[8]}]
set_property PACKAGE_PIN D1 [get_ports {dac_lower_o[9]}]

set_property PACKAGE_PIN G4 [get_ports {dac_upper_o[0]}]
set_property PACKAGE_PIN J14 [get_ports {dac_upper_o[1]}]
set_property PACKAGE_PIN L13 [get_ports {dac_upper_o[2]}]
set_property PACKAGE_PIN M13 [get_ports {dac_upper_o[3]}]
set_property PACKAGE_PIN J11 [get_ports {dac_upper_o[4]}]
set_property PACKAGE_PIN N14 [get_ports {dac_upper_o[5]}]
set_property PACKAGE_PIN K11 [get_ports {dac_upper_o[6]}]
set_property PACKAGE_PIN M5 [get_ports {dac_upper_o[7]}]
set_property PACKAGE_PIN K12 [get_ports {dac_upper_o[8]}]
set_property PACKAGE_PIN M11 [get_ports {dac_upper_o[9]}]
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

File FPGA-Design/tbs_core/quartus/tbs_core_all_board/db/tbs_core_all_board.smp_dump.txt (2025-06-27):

State Machine - |tbs_core_all_board|tbs_core_all:tbs_core_0|state
Name state.main_sampling state.wait_for_trigger_2 state.ignore_trigger_1 state.wait_for_trigger_1 state.wait_for_dac state.main_init state.main_idle state.main_reset 
state.main_reset 0 0 0 0 0 0 0 0 
state.main_idle 0 0 0 0 0 0 1 1 
state.main_init 0 0 0 0 0 1 0 1 
state.wait_for_dac 0 0 0 0 1 0 0 1 
state.wait_for_trigger_1 0 0 0 1 0 0 0 1 
state.ignore_trigger_1 0 0 1 0 0 0 0 1 
state.wait_for_trigger_2 0 1 0 0 0 0 0 1 
state.main_sampling 1 0 0 0 0 0 0 1 

State Machine - |tbs_core_all_board|tbs_core_all:tbs_core_0|ethernet:ethernet_0|ethernet_rx:ethernet_rx_entity|ethernet_rx_controller:ethernet_rx_controller_0|current_state
Name current_state.IGNOREPACKET current_state.RECEIVING_CRC current_state.RECEIVING_PAYLOAD current_state.RECEIVING_HEADER current_state.IDLE 
current_state.IDLE 0 0 0 0 0 
current_state.RECEIVING_HEADER 0 0 0 1 1 
current_state.RECEIVING_PAYLOAD 0 0 1 0 1 
current_state.RECEIVING_CRC 0 1 0 0 1 
current_state.IGNOREPACKET 1 0 0 0 1 

State Machine - |tbs_core_all_board|tbs_core_all:tbs_core_0|ethernet:ethernet_0|ethernet_tx:ethernet_tx_entity|ethernet_tx_controller:eth_transmit_data|current_state
Name current_state.SENDING_CRC current_state.SENDING_PAYLOAD current_state.SENDING_HEADER current_state.IDLE 
current_state.IDLE 0 0 0 0 
current_state.SENDING_HEADER 0 0 1 1 
current_state.SENDING_PAYLOAD 0 1 0 1 
current_state.SENDING_CRC 1 0 0 1 

State Machine - |tbs_core_all_board|tbs_core_all:tbs_core_0|uart:uart_0|uart_rx:uart_rx_0|rx_state
Name rx_state.STOPBIT rx_state.RECEIVING rx_state.STARTBIT rx_state.IDLE 
rx_state.IDLE 0 0 0 0 
rx_state.STARTBIT 0 0 1 1 
rx_state.RECEIVING 0 1 0 1 
rx_state.STOPBIT 1 0 0 1 

State Machine - |tbs_core_all_board|tbs_core_all:tbs_core_0|uart:uart_0|uart_tx:uart_tx_0|tx_state
Name tx_state.STOPBIT tx_state.TRANSMITTING tx_state.STARTBIT tx_state.STARTTX tx_state.IDLE 
tx_state.IDLE 0 0 0 0 0 
tx_state.STARTTX 0 0 0 1 1 
tx_state.STARTBIT 0 0 1 0 1 
tx_state.TRANSMITTING 0 1 0 0 1 
tx_state.STOPBIT 1 0 0 0 1 

State Machine - |tbs_core_all_board|tbs_core_all:tbs_core_0|debouncer:debouncer_6|state
Name state.debouncer_wait_high state.debouncer_wait_low state.debouncer_idle 
state.debouncer_idle 0 0 0 
state.debouncer_wait_low 0 1 1 
state.debouncer_wait_high 1 0 1 

State Machine - |tbs_core_all_board|tbs_core_all:tbs_core_0|debouncer:debouncer_5|state
Name state.debouncer_wait_high state.debouncer_wait_low state.debouncer_idle 
state.debouncer_idle 0 0 0 
state.debouncer_wait_low 0 1 1 
state.debouncer_wait_high 1 0 1 

State Machine - |tbs_core_all_board|tbs_core_all:tbs_core_0|debouncer:debouncer_4|state
Name state.debouncer_wait_high state.debouncer_wait_low state.debouncer_idle 
state.debouncer_idle 0 0 0 
state.debouncer_wait_low 0 1 1 
state.debouncer_wait_high 1 0 1 

State Machine - |tbs_core_all_board|tbs_core_all:tbs_core_0|debouncer:debouncer_3|state
Name state.debouncer_wait_high state.debouncer_wait_low state.debouncer_idle 
state.debouncer_idle 0 0 0 
state.debouncer_wait_low 0 1 1 
state.debouncer_wait_high 1 0 1 

State Machine - |tbs_core_all_board|tbs_core_all:tbs_core_0|debouncer:debouncer_2|state
Name state.debouncer_wait_high state.debouncer_wait_low state.debouncer_idle 
state.debouncer_idle 0 0 0 
state.debouncer_wait_low 0 1 1 
state.debouncer_wait_high 1 0 1 

State Machine - |tbs_core_all_board|tbs_core_all:tbs_core_0|debouncer:debouncer_1|state
Name state.debouncer_wait_high state.debouncer_wait_low state.debouncer_idle 
state.debouncer_idle 0 0 0 
state.debouncer_wait_low 0 1 1 
state.debouncer_wait_high 1 0 1 

State Machine - |tbs_core_all_board|tbs_core_all:tbs_core_0|debouncer:debouncer_0|state
Name state.debouncer_wait_high state.debouncer_wait_low state.debouncer_idle 
state.debouncer_idle 0 0 0 
state.debouncer_wait_low 0 1 1 
state.debouncer_wait_high 1 0 1 

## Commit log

2025-06-27 initial files commit
    [749013011A.step, A-Headers.SchDoc, AD5331BRUZ.step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]
2025-07-27 added Measurements/Generate_ECG folder
    [ecg_data.csv, ecg_data_0.15V_3.15V.csv, ecg_data_0.3V_2.4V.csv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]

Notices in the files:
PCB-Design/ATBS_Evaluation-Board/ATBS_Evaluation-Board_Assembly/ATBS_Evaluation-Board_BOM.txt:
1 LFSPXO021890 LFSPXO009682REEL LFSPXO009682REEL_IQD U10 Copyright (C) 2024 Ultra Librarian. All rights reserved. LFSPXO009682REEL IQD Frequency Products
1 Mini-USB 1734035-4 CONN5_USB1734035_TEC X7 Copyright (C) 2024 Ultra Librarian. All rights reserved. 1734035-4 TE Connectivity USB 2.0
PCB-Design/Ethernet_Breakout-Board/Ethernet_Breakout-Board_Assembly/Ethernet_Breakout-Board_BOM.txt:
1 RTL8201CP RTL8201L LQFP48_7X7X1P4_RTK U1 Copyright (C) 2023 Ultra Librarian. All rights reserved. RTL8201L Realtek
